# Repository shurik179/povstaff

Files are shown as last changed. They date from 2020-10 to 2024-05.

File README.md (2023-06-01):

# POV staff
This repository contains all files related to Persistence of Vision (POV) staff project. A detailed write-up of Version 1 of this project is available on  Instructables at [https://www.instructables.com/Persistence-of-Vision-LED-Staff/](https://www.instructables.com/Persistence-of-Vision-LED-Staff/); you can also find there photos  of the staff in action.

The latest version (as of June 1, 2023) is 4.1. It is documented at
https://povstaff.readthedocs.io

## Structure of this repository  
This repository is organized as follows:

* `docs`: documentation
* `code`: this directory contains the source code for the staff software
* `hardware`:  design files for the custom PCBs used in
  the project, as well as STEP files for the 3d printed components.
* `images`: sample image(s) and  `imagelist.txt` file

## Authors and license
This project was created by Alexander Kirillov <irobotics.store@gmail.com>; it is
based on [earlier work](https://learn.adafruit.com/pov-dotstar-double-staff) of
Phillip Burgess and Erin St Blaine from Adafruit. The project is available under
MIT license; see LICENSE file for details.

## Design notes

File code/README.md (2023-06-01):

# POV Staff Software

This folder contains software for POV Staff project, V4.  It is intended to be complied
and uploaded to the QT Py ESP32-S3 (or QT Py ESP32-S2) using Arduino IDE  version
1.8 or later.   You will need the following libraries:

  * POV-ESP32 library from  https://github.com/shurik179/pov-esp32

  * Adafruit DotStar

  * Adafruit NeoPixel

  * ESPxWebFlMgr from   https://github.com/holgerlembke/ESPxWebFlMgr

You will need the arduino core for ESP32, see https://learn.adafruit.com/adafruit-qt-py-esp32-s2/arduino-ide-setup
for installation instructions.

Make sure that you choose the following options in the Arduino IDE tools menu
(for ESP32-S3):

* Partition scheme: *Default (3MB APP/1.5MB SPIFFS)*

* Erase All Flash Before Sketch Upload: *Disabled*

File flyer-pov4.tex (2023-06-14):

% !TEX TS-program = pdflatex
% !TEX encoding = UTF-8 Unicode

% This is a simple template for a LaTeX document using the "article" class.
% See "book", "report", "letter" for other types of document.

\documentclass[10pt,letter, landscape]{article} % use larger type; default would be 10pt

\usepackage[utf8]{inputenc} % set input encoding (not needed with XeLaTeX)
\usepackage{graphicx} % support the \includegraphics command and options
\usepackage[T1]{fontenc}
\usepackage[scaled=1.0]{helvet}
\renewcommand*\familydefault{\sfdefault} %% Only if the base font of the document is to be sans serif

\usepackage[newdimens]{labels}
\LabelCols=3% Number of columns of labels per page
\LabelRows=2% Number of rows of labels per page
\LeftPageMargin=8mm% These four parameters give the
\RightPageMargin=8mm% page gutter sizes. The outer edges of
\TopPageMargin=8mm% the outer labels are the specified
\BottomPageMargin=8mm% distances from the edge of the paper.
\InterLabelColumn=0mm% Gap between columns of labels
\InterLabelRow=0mm% Gap between rows of labels
\LeftLabelBorder=6mm% These four parameters give the extra
\RightLabelBorder=6mm% space used around the text on each
\TopLabelBorder=6mm% actual label.
\BottomLabelBorder=6mm%
\numberoflabels=6
\LabelInfotrue
\LabelGridtrue

%\renewcommand{\baselinestretch}{1.2}

\begin{document}%
\genericlabel{%
\noindent\begin{minipage}{70mm}
    %\vspace*{-15mm}
\centerline{}
\medskip
\centerline{\Large\bf POV staff  kit V4}

\centerline{\tt{tindie.com/products/21633/}}

\medskip

Thank you for your order of POV staff kit! \\ Please visit \quad
{\tt povstaff.readthedocs.io}

for detailed instructions.

If you have any questions or comments, or need replacement for a part you have misplaced or damaged,  please email us at

\centerline{\tt{irobotics.store@gmail.com}}

%\medskip

To connect to the staff use WiFi network name and password below:

\vspace*{1.1cm}

Best, \\Island Robotics

\end{minipage}
}

\end{document}

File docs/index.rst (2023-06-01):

###############################
Persistence of Vision LED staff
###############################
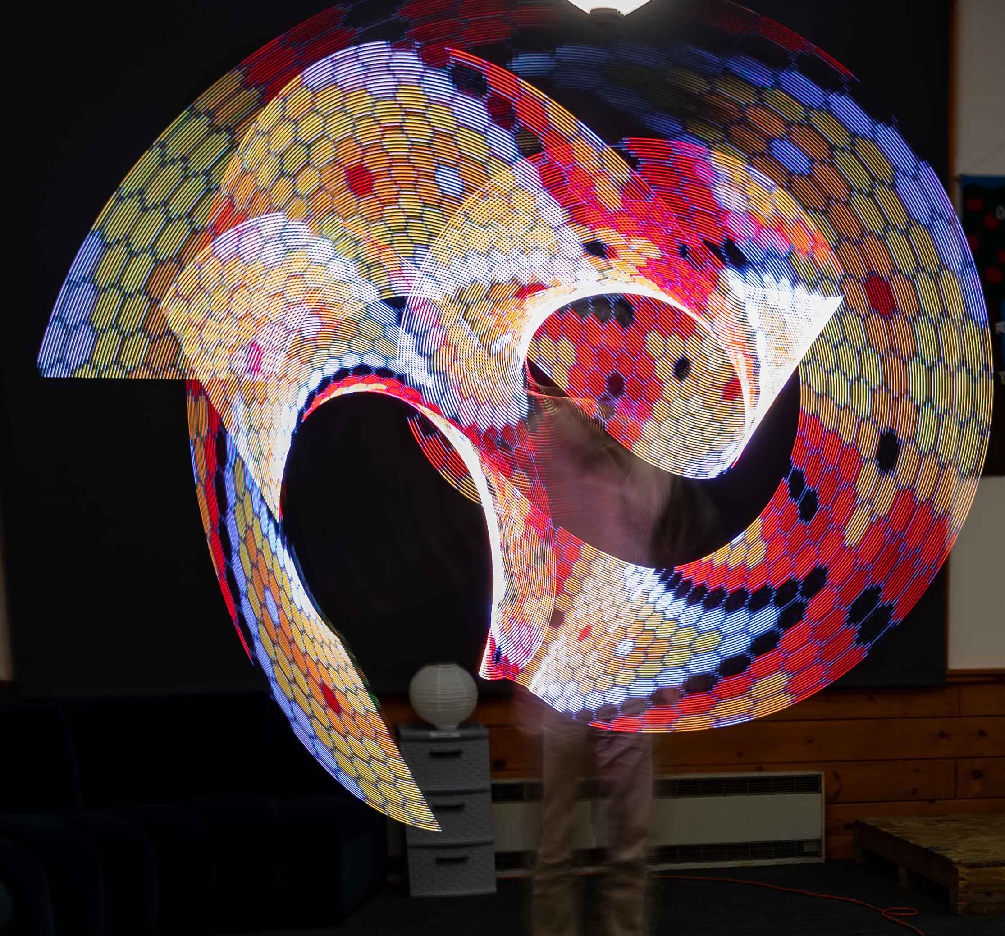
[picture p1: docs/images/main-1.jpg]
POV staff in action


This guide contains documentation for Persistence of Vision (POV) LED staff project,
created by Alexander Kirillov <irobotics.store@gmail.com>.

This document describes version 4.1, which was released on May 10, 2023.  An
earlier version of this project was documented on
`Instructables web site <https://www.instructables.com/Persistence-of-Vision-LED-Staff/>`__.
The version described here contains several improvements compared to the earlier
one, see below.

For those wishing to reproduce this project, we are offering a kit of parts for
sale through our `Tindie store <https://www.tindie.com/stores/irobotics/>`__.
However, all design files, software, BOM and more are published under open
source license, so anyone can build their own version from scratch. You can
find these files in the project GitHub repository: https://github.com/shurik179/povstaff

Overview
********

It is well known that even after a light has been turned off, human eye keeps
"seeing" it for a fraction of second. This is known as Persistence of Vision, or
POV, and it allows one to "paint" pictures by quickly moving a strip of LEDs,
drawing one line of an image at a time in quick succession. If you search online
(e.g. on Etsy), you can find quite a few toys based on this idea: pois, staffs, and more.

However, these are expensive: typical prices for a POV staff of decent
resolution start at $500, and they use proprietary software, so there is no easy
way to modify their behavior or add extra functionality. Thus, when looking for
a birthday gift for a friend who enjoys painting with light, I decided to create
my own open source version using readily available components.

My project builds upon the outstanding `work of Phillip Burgess and Erin St Blaine
<https://learn.adafruit.com/pov-dotstar-double-staff>`__
from Adafruit; however, I made a few changes, upgrading the electronics.

Key Features
************

* It is a two-sided staff, of total length 141 cm (55in); it is not collapsible.
  Each side of the staff has two 50cm/72 pixels LED strips, for the total of 288 LEDs.
  Thus, you can use it to show images with 72-px resolution.

* Staff is powered by two 18650 Li-Ion batteries, which should be enough for at
  least 1 hr show, possibly as much as 2 hours, depending on intensity of your
  images. The batteries can be recharged via 5.5mm/2.1 barrel connector (or USB
  C cable, using included adapter); full charge time is about 5 hrs.

* Images (in bitmap format) can be easily uploaded to the staff over WiFi. It has
  enough memory for about 50 images. The order in which images are shown is
  described in a separate plain text file, where you can put a list of
  images and durations. An image can be listed there several times, or none at all.

* The staff contains an Inertial Motion Unit (IMU) which can be used to detect
  when the staff is in motion. The software uses it to adjust update frequency
  for images, so the images will not appear stretched or compressed regardless
  of how fast you are rotating it. You can also use it for controlling your
  show: e.g. stopping the staff vertically is used as a signal to move to the
  next image in the slideshow.

* The software is based on Arduino IDE. It is available under an open source
  license and is easy to modify to suit your needs.

Differences from  version 3
****************************

* New MCU (ESP32-S3 QT Py)

* Wireless uploading of images

* Many changes to wiring

* New 3d printed spacers and other components, printed in black resin.

* Foam protectors at the ends of the staff, to protect the staff when dropped

.. toctree::
    :caption: Table of Contents
    :maxdepth: 2

    build
    usage
    license

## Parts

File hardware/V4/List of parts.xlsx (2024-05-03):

 | Name | Needed per kit | Price per kit | Vendor | URL
 | QT Py ESP32-S3 | 1 | $11.25 | Adafruit | https://www.adafruit.com/product/5426
Electronics | POVshield |  | $4.00 | JLCPCB
 | POVswitchboard |  | $1.00 | JLCPCB
 | PDB-switch |  |  | JLCPCB
 | PDB-charge |  |  | JLCPCB
3d printed | battery midspacer | 1 | $1.40 | JLCPCB 3d print
 | battery endspacer | 2 | $2.80 | JLCPCB 3d print
 | Charge spacer | 1 | $2.20 | JLCPCB 3d print
 | Switch spacer | 1 | $2.20 | JLCPCB 3d print
 | Endspacer - charge | 1 | $2.40 | JLCPCB 3d print |  | Printed in black resin
 | Endspacer-switch | 1 | $2.40 | JLCPCB 3d print
 | tool |  |  | DIY
Connectors | 2x3header, male | 2 | $1.30 | Digikey | https://www.digikey.com/en/products/detail/samtec-inc/TSW-103-08-F-D/6691696
 | 2x3 header female, 90 deg | 2 | $1.80 | Digikey | https://www.digikey.com/en/products/detail/samtec-inc/SSQ-103-02-T-D-RA/1111310
 | 7 pin male hader, 11.4 mm long, double spacer | 2 | $1.00 | Aliexpress | https://www.aliexpress.us/item/2251832709911024.html
 | switch | 1 | $0.92 | Mouser | https://www.mouser.com/ProductDetail/612-RRA1534400
 | Charge connector |  | $0.30 | Aliexpress | https://www.aliexpress.us/item/3256802811672166.html
 | USB C to barrel plug adapter |  | $1.00 | Aliexpress | https://www.aliexpress.us/item/3256804389121490.html
Wires | 2-pin XH pigtails | 2 | $0.90 | Amazon | https://www.amazon.com/gp/product/B096F5LSVL
 | 4-pin 22 AWG wire | 22 cm |  | Aliexpress | https://www.aliexpress.us/item/2255800087895459.html
 | 2-pin 20 AWG wire | 55.5cm |  | Aliexpress
 | 2-pin 24 AWG wire | 55.5 cm |  | Aliexpress
LED | SK9822 LED strip, 144pixels/m,black, IP30 | 2 | $34.00 | Aliexpress | https://www.aliexpress.us/item/2251832136012227.html | https://www.aliexpress.us/item/3256805036306271.html
End protection | Foam tubing, 28mm ID, 38mm OD | 2x3cm | $1.30 | Amazon | https://www.amazon.com/gp/product/B0951ZLSJL
 | Heat Shrink Wrap Tubing, 40mm diameter, black | 2x5.5cm | $1.00 | Amazon | https://www.amazon.com/gp/product/B07FVRT9JS
 | Tennis Overgrip tape | 1 pc | $2.00 | Amazon | https://www.amazon.com/gp/product/B001OTC4K0/
Total |  |  | $75.17

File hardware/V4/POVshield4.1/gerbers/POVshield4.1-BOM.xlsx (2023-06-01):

Designator | Footprint | Comment | JLCPCB Part #（optional）
C1,C2,C3 | C_0805_2012Metric | 10uF | C15850
C4,C5 | C_0603_1608Metric | 100nF | C14663
D1 | LED_0603_1608Metric | LED | C72038
R1 | R_0603_1608Metric | 2k | C22975
R2 | R_0603_1608Metric | 1.2k | C22765
R3,R4,R5 | R_0603_1608Metric | 3.3k | C22978
R6,R7 | R_0603_1608Metric | 10k | C25804
U2 | Bosch_LGA-14_3x2.5mm_P0.5mm | LSM6DSO | C2829074
U1 | HSOP-8-1EP_3.9x4.9mm_P1.27mm_EP2.41x3.1mm_ThermalVias | TP4056 | C16581

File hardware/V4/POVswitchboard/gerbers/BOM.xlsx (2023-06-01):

Designator | Footprint | Comment | JLCPCB Part #（optional）
C2 | C_0805_2012Metric | 10uF

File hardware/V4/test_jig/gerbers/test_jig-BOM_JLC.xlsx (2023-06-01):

Comment | Designator | Footprint | JLCPCB Part #（optional）
SK9822-EC2020 LED | D1,D2,D3,D4,D5,D6,D7,D8,D9,D10,D11,D12,D13,D14,D15 | 2020 | C2909059

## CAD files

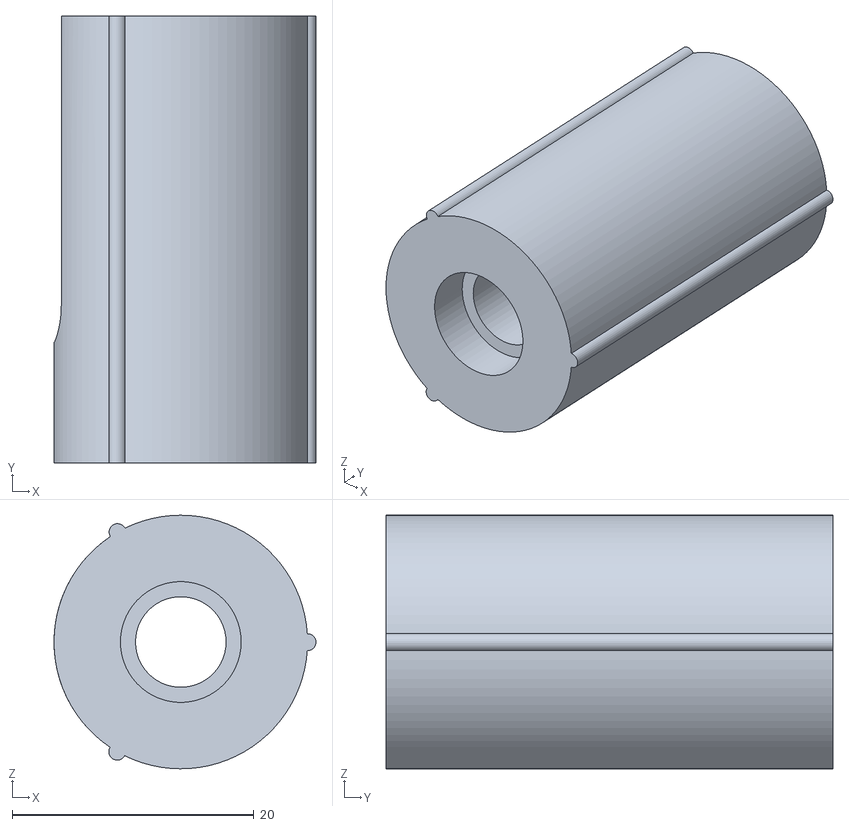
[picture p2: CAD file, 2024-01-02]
hardware/V4/3d-printed/Charger_spacer_2024.01.02.stl
21.7 x 37.0 x 21.0

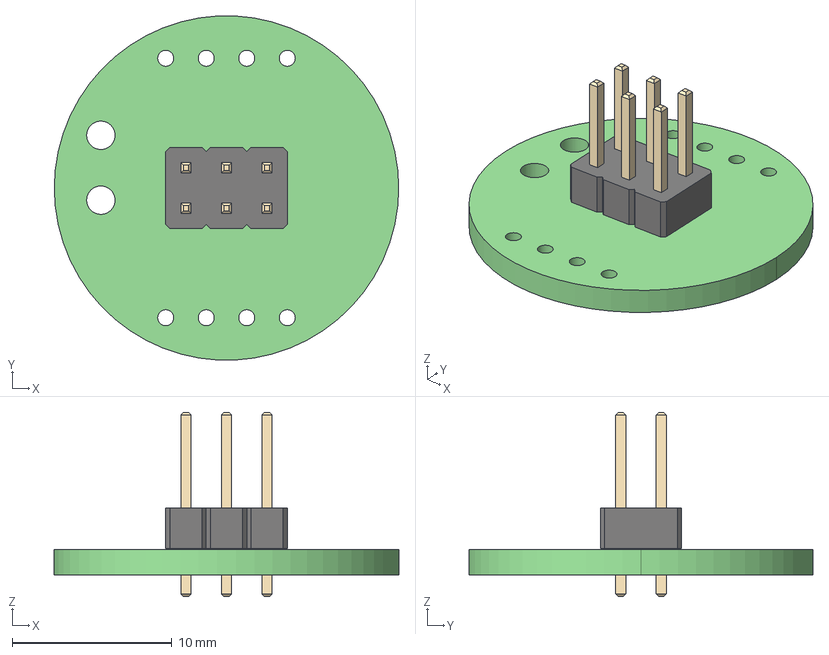
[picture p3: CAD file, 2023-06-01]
hardware/V4/PDB4-CHARGE/PDB4-CHARGE.step
21.6 x 21.6 x 11.5 mm
PDB4-CHARGE PCB

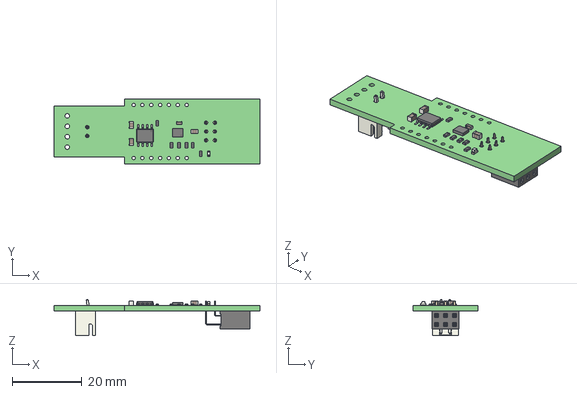
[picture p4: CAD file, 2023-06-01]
hardware/V4/POVshield4.1/POVshield4.1.STEP
59.2 x 18.8 x 10.4 mm
_autosave-POVshield4 PCB

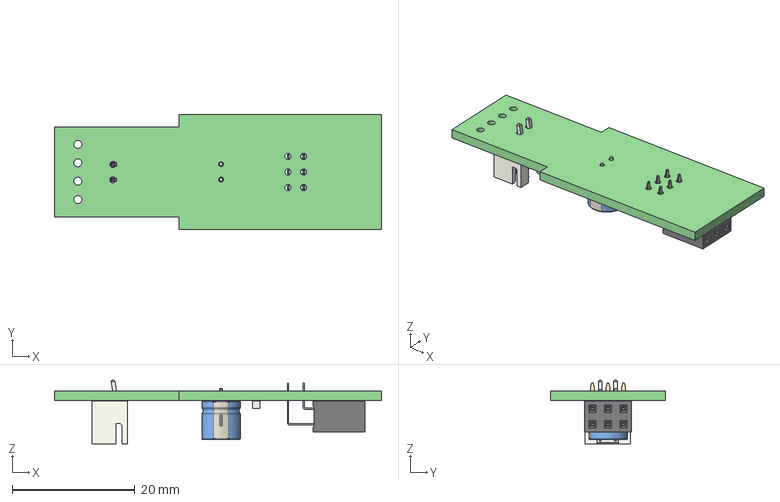
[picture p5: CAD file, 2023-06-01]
hardware/V4/POVswitchboard/POVswitchboard.STEP
53.3 x 18.8 x 10.4 mm
POVswitchboard PCB

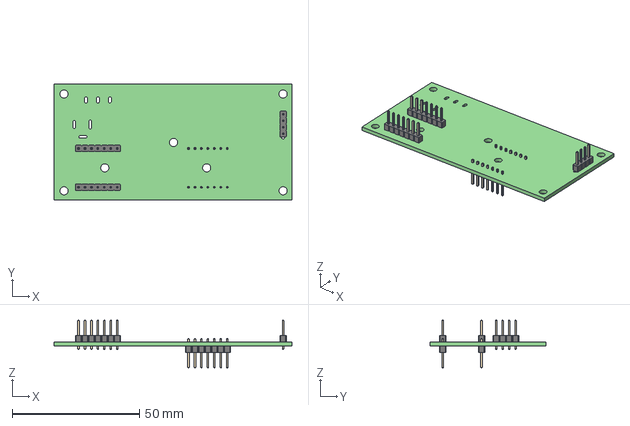
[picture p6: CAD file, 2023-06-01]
hardware/V4/test_jig/test_jig.STEP
93.4 x 45.7 x 18.8 mm
test_jig PCB

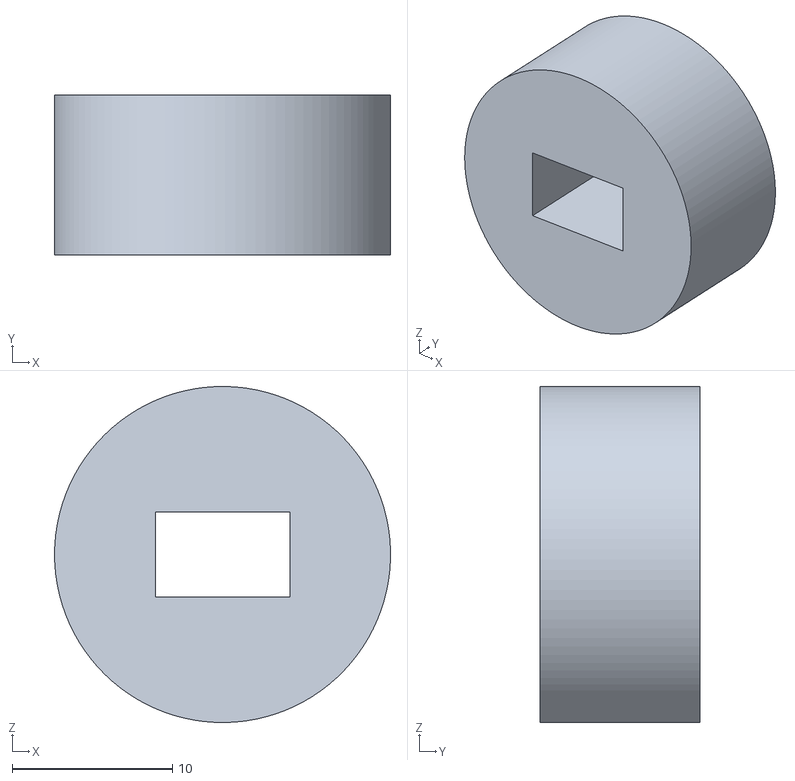
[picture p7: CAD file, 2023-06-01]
hardware/V4/3d-printed/PDB tool_2023.04.26.stl
21.0 x 10.0 x 21.0

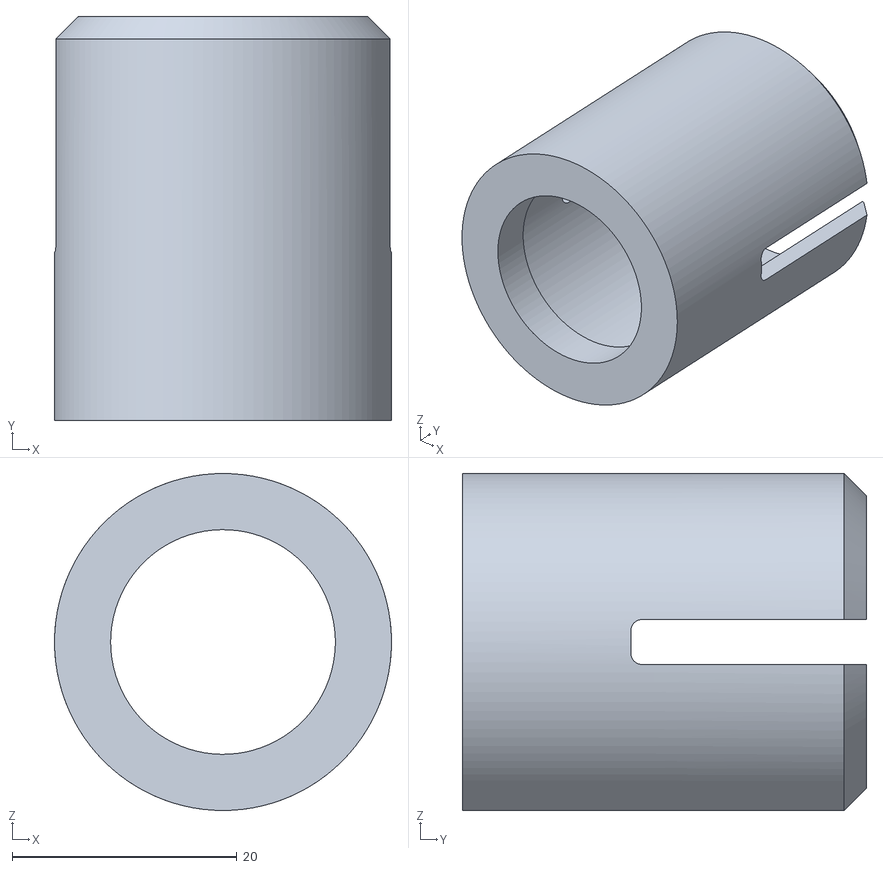
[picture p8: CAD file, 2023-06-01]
hardware/V4/3d-printed/Endcap_switch_2023.04.26.stl
30.0 x 36.0 x 30.0

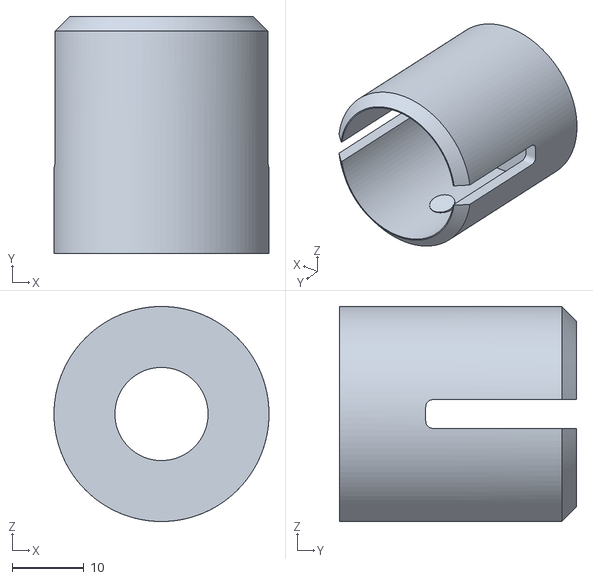
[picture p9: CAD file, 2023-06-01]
hardware/V4/3d-printed/Endcap_charger_2023.04.26.stl
30.0 x 33.0 x 30.0

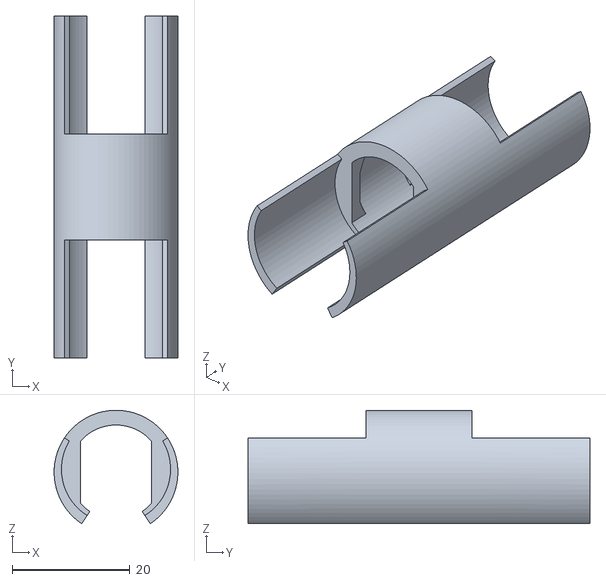
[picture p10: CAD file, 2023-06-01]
hardware/V4/3d-printed/Battery_midspacer_2023.04.26.stl
21.0 x 58.0 x 19.2

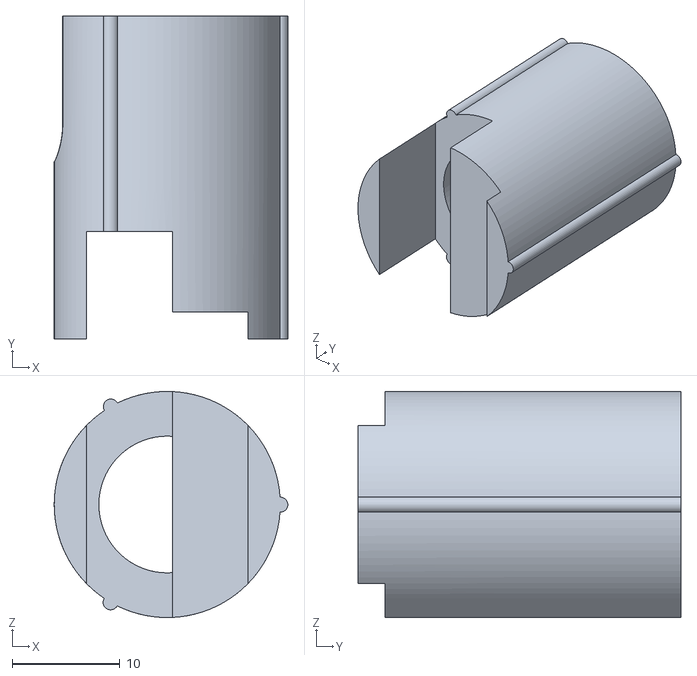
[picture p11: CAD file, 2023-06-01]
hardware/V4/3d-printed/Switch_spacer_2023.04.26.stl
21.7 x 30.0 x 21.0

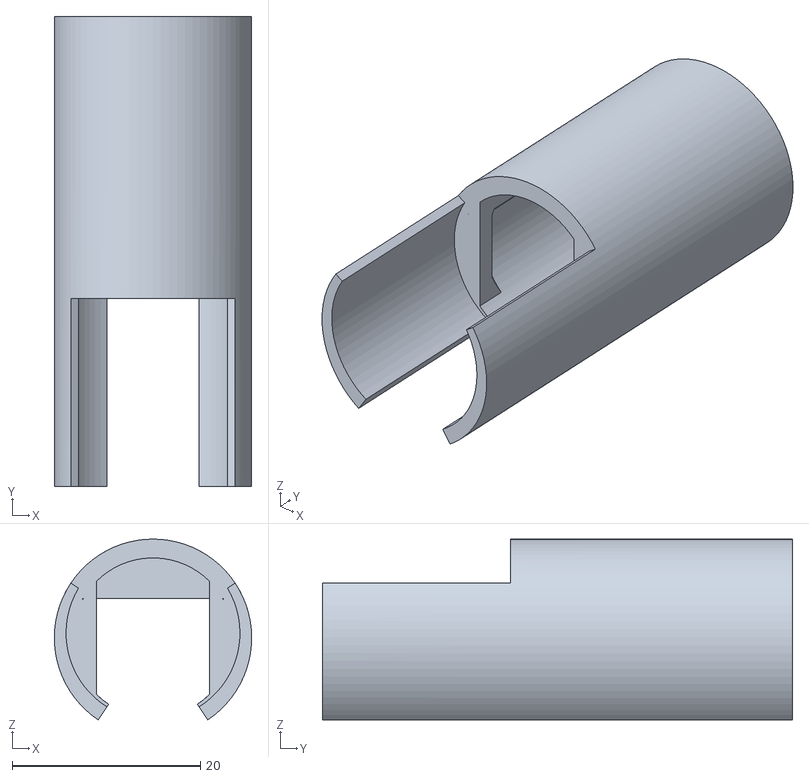
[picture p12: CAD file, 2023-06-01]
hardware/V4/3d-printed/Battery_endspacer_2023.04.26.stl
21.0 x 50.0 x 19.2

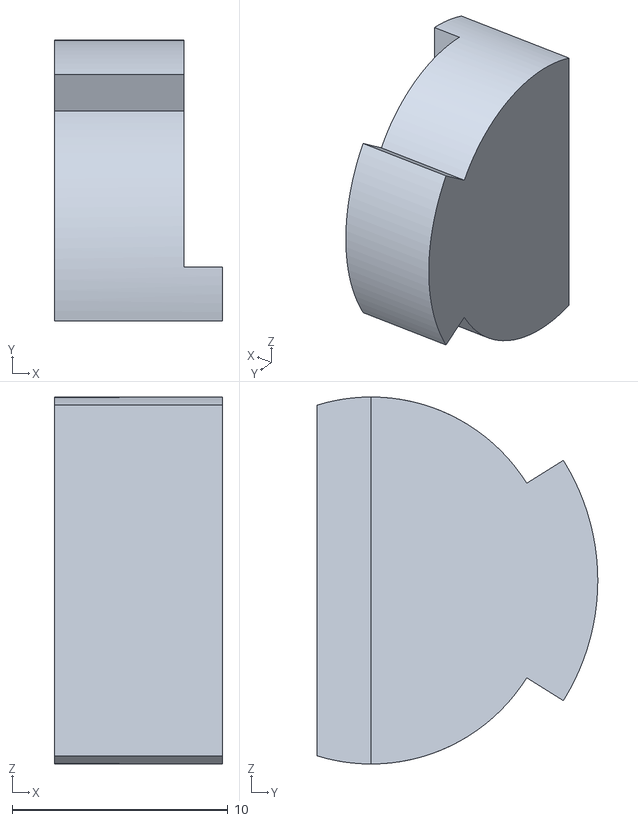
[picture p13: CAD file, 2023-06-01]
hardware/V4/3d-printed/plug_2023.04.26.stl
7.80 x 13.0 x 17.0

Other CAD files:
hardware/V4/3d-printed/Battery_endspacer_2023.04.26.f3d
hardware/V4/3d-printed/Battery_midspacer_2023.04.26.f3d
hardware/V4/3d-printed/Charger_spacer_2024.01.02.f3d
hardware/V4/3d-printed/Endcap_charger_2023.04.26.f3d
hardware/V4/3d-printed/Endcap_switch_2023.04.26.f3d
hardware/V4/3d-printed/PDB tool_2023.04.26.f3d
hardware/V4/3d-printed/Switch_spacer_2023.04.26.f3d
hardware/V4/3d-printed/plug_2023.04.26.f3d

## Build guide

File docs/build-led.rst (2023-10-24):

Step 2: LED assemblies
======================

**Materials and tools:**

* Wood dowels with attached PDBs (from step 1)

* LED strips

* 22AWG solid core wire (from bag A in kit of parts)

**Steps:**

1. Get the LED strip(s). If they have any wires soldered, de-solder them; remove
   excess solder using a braid wick. If you ordered 1m or 2m strips, cut them into
   50 cm pieces, making sure to leave as large as possible soldering pads in the
   beginning of each strip (this should be easy, as usually longer strips are
   created by soldering together 50cm ones, so you will be just undoing someone
   else's work).

2. Tin the pads in the beginning of each LED strip.
   **Warning: LED strips are directed!! in each strip, the signal goes in one
   direction only, as indicated by the arrows. You should tin the pads in the
   beginning of the strip, so that arrows go from tinned pads to the opposite
   end - see photos below.** 

3. Solder 2cm long pieces of 22AWG wire to each of the pads. The easiest way to
   do it is as follows:

   * Strip 2cm of insulation from the end of wire; do not cut it yet.

   * Holding the wire by insulated part, solder the stripped end to the pad.
     You will be soldering very close to the first LED, so please watch your
     iron carefully - do not touch the LED!

   * Cut the wire. To make the next steps easier, trim the wires so that they
     are of different lengths (length of each should be at least 1 cm)

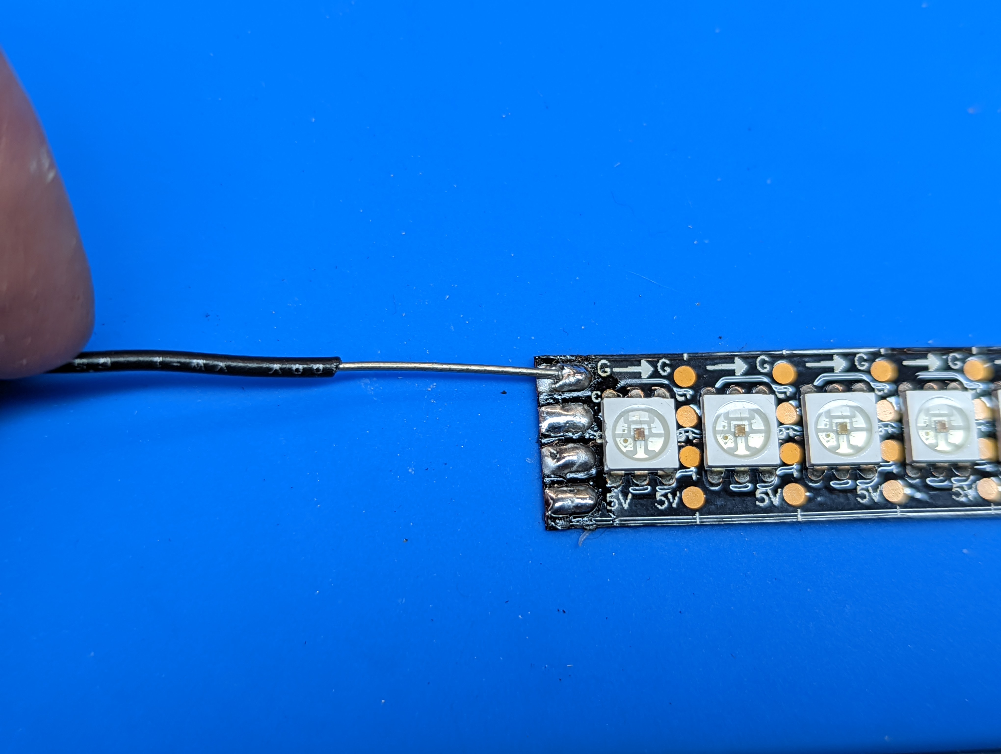
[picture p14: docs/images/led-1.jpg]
    

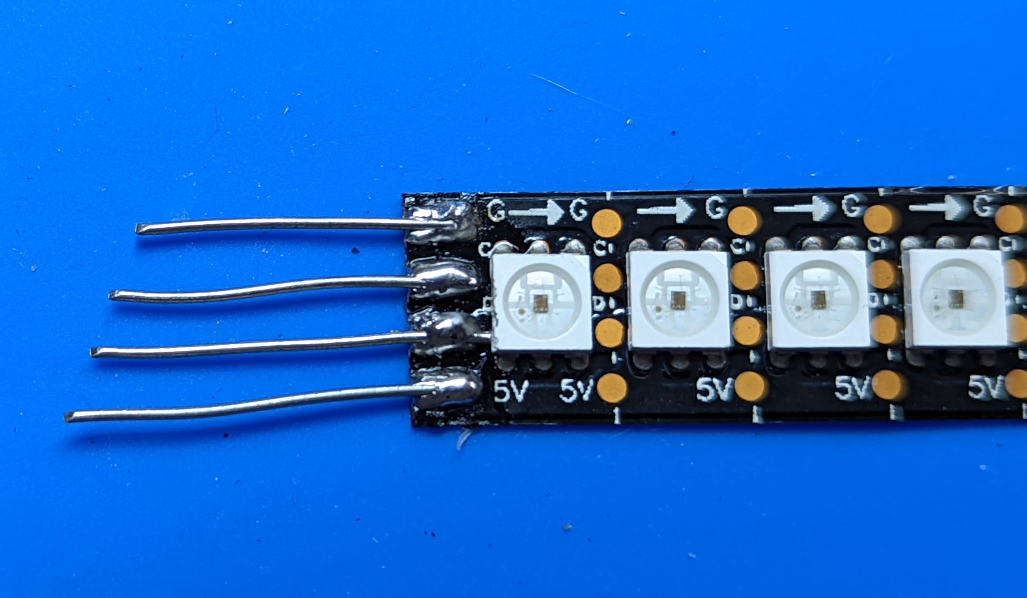
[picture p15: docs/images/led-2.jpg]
    

4.  Remove  the  backing paper from the first 5-10 cm of adhesive strip on the back
    of the LED. Insert the soldered wires into the holes of the power distribution
    board you had previously attached to the wood dowels and
    attach the strip to the wood dowel, aligning it so that the
    beginning of the strip is about 5mm away from the power distribution board.
    Remove the remaining backing paper and attach the strip to the dowel.

5.  Solder the wires to the power distribution board. Trim them using flush cutters.
    Repeat the previous steps for all 4 LED strips, placing two LED strips on
    each dowel, on opposite sides of the dowel.

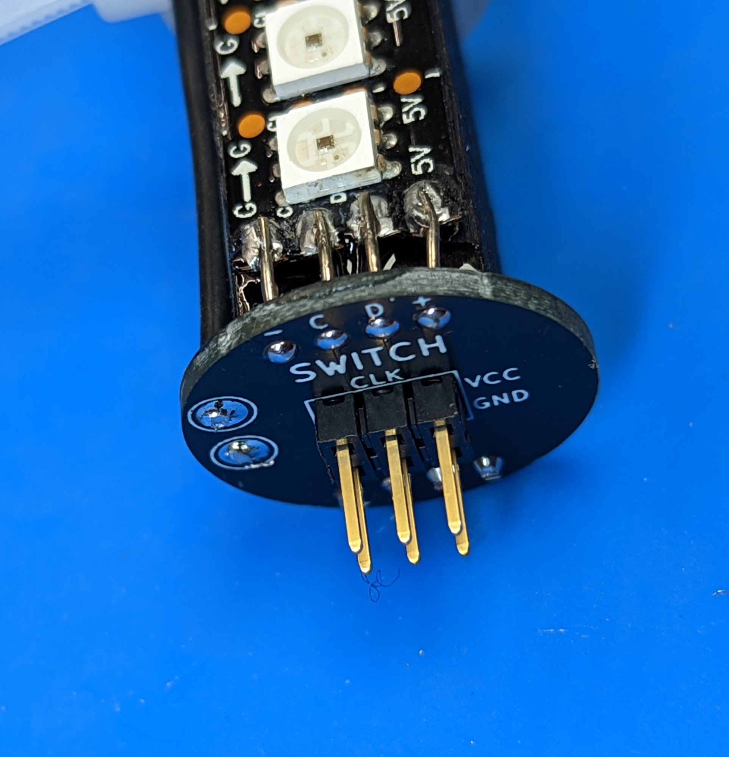
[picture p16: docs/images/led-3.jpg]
   

**Note**: the adhesive on LED strips is not very strong, so your strips might
start peeling off. It is OK; we will make a more permanent attachment later.

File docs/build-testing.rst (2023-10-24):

Step 8: Testing
===============================
Before continuing, let us do the final test. Make sure to clear large area on
your desk or floor for this step.

Take the controller assembly you had created in the previous step and plug it
into the LED assemblies as follows:

* The POV controller shield with the QT Py should be plugged into the LED assembly
  labeled CHARGE.

* The switch connector  board should be plugged into the LED assembly labeled SWITCH

**The LED assemblies are not interchangeable!**

In each case, the board must be plugged into PDB so that the label CHARGE (or SWITCH)
should be above the plugged board:

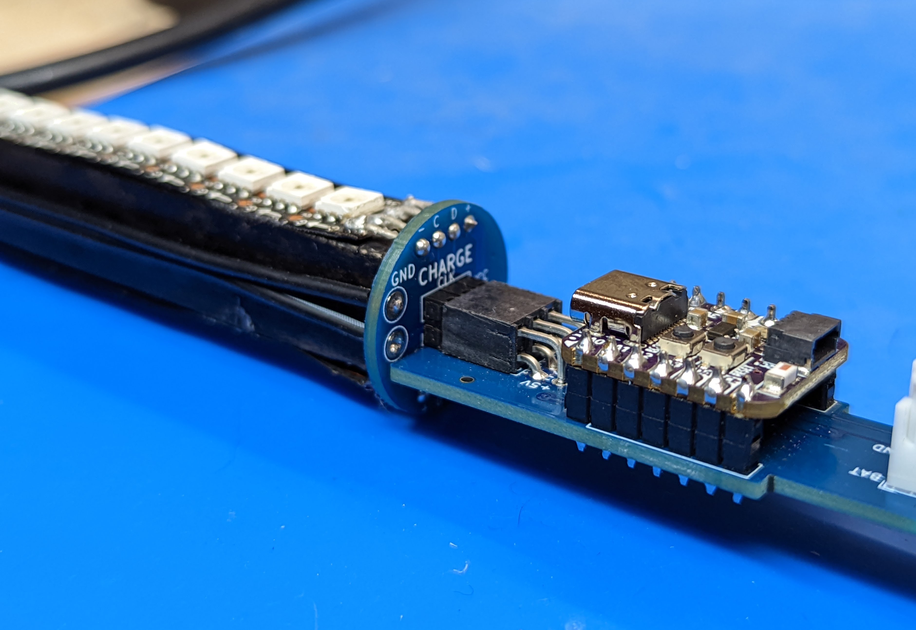
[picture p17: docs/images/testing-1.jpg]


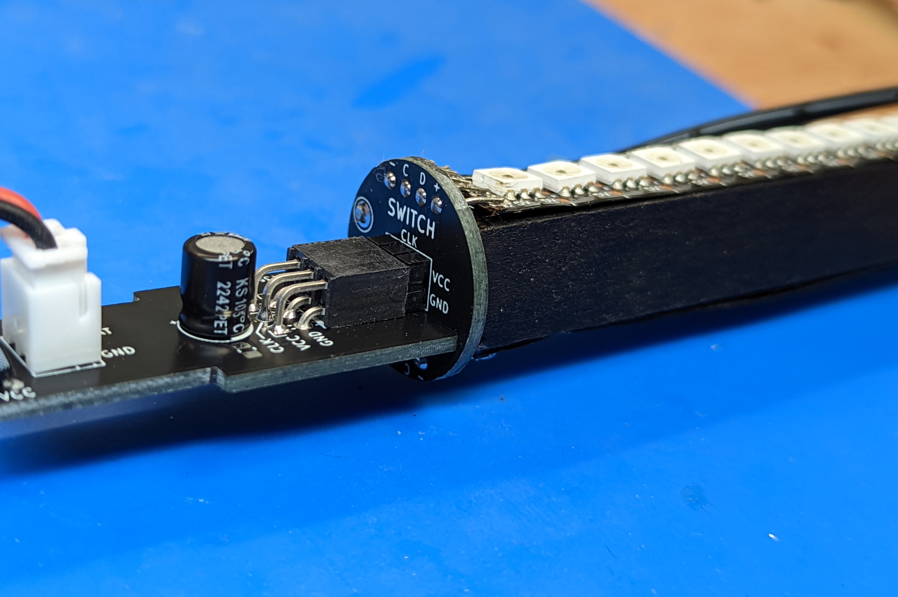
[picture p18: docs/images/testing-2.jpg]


Double-check that everything is plugged correctly. Make sure that the switch at
the end of SWITCH LED assembly is in the middle (Off) position.

Now, take the batteries. Plug the battery connectors into the 2-pin JST XH
connectors on the POV shield board and the switch board (doesn't matter which battery goes into which board).

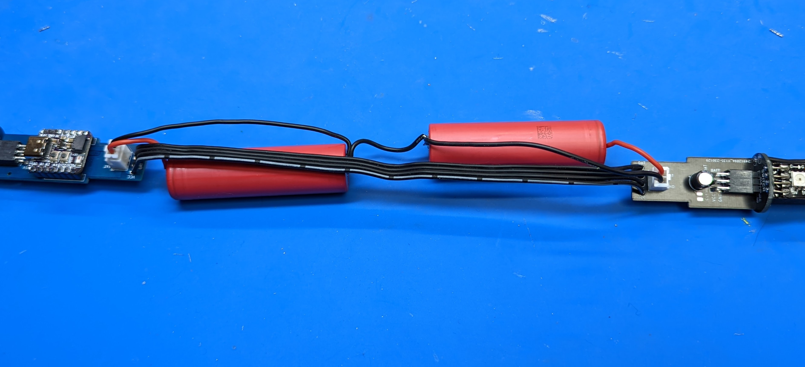
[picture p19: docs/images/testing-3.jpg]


Turn the switch on (you will have to try both positions to figure out which of them is ON).

The staff should come to life; it will show the battery voltage, by
lighting part of the LED strips. The longer the strip, the higher the battery charge.

Note: the software uses the motion sensor (IMU). If you turn the staff on while the
staff (to be precise, the electronics board containing the motion sensor) is horizonal,
the staff goes into charging mode, so it will show the battery voltage but will not
show any images. If you want to test images, make switch the staff on holding
the sensor board vertical. See User guide for details.

If this works, you can turn the staff off and  proceed to the next step.

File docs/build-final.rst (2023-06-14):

Step 10: Final assembly
===============================

**Materials:**

* LED assemblies, from previous steps

* battery and controller assembly, from step 9

* bag F:

  Kit of parts, bag F

  1.  two shrink wrap sleeves

  2. two foam sleeves

  3. Switch end protector

  4.  Charge  end protector

  5. tennis grip tape

  6. Foam washers

* Clear polycarbonate tube (11F/141 cm), from flowtoys.com

**Steps:**

1. Make sure you have a large area to work.
   Lay out the LED assemblies, battery and electronics assembly. Make sure that
   the switch at the end of SWITCH LED assembly is in middle (OFF) position.

2. Plug the battery assembly into the LED assemblies. As before, the side which
   contains QT Py MCU should be plugged into the CHARGE LED assembly, and the
   other side, into the SWITCH LED assembly. In each case, the board must be
   plugged into PDB so that the label CHARGE (or SWITCH) should be above the
   plugged board:

   Connecting LED assemblies

   Connecting LED assemblies

3. Double-check that everything is plugged correctly. Do the final test: turn
   the switch on. The LEDs should briefly light up, showing the battery charge.
   If they don't, check the troubleshooting section.
   If everything is OK, turn the switch off and proceed.

4. Start inserting the whole assembly into the tube, CHARGE end  first. Do it
   slowly. If you meet with resistance, push gently; if it is not enough, do
   not use excessive force - try to locate the problem. If necessary, remove
   from the tube and fix the wiring or electric tape. Watch that the LED assembly
   does not get  disconnected from the battery and electronics assembly.
   Continue until everything is fully in. Push to fully insert the switch; make
   sure the switch retaining tabs are inside the tube.
   If everything worked as expected, the charge connector should now be level with the
   opposite end of the tube or several millimeters inside the tube. In the
   latter case, use the included foam washers to fill the rest of the tube.

5. Take the 3d printed switch end protector (item 3 in bag F, the one with larger
   opening). For shipping, it might have been placed inside the foam wrap;
   if so, remove it from the foam wrap.  Put it over the
   switch end of tube. There are two small bumps inside the protector which
   should go into the holes in the tube; if necessary, turn the end protector
   until you hear the click.

6. Repeat the same with the charge switch protector (item 4 in the bag), putting it
   on the opposite end of the tube. Test the whole staff once again, turning it
   on and off.

7. Put the two pieces of the foam tube over the end protectors so that the foam
   tube extends beyond the protector by 2-3 mm. In 2-3 places, put some epoxy (or crazy glue)
   between the foam and the 3d-printed  end protector. 

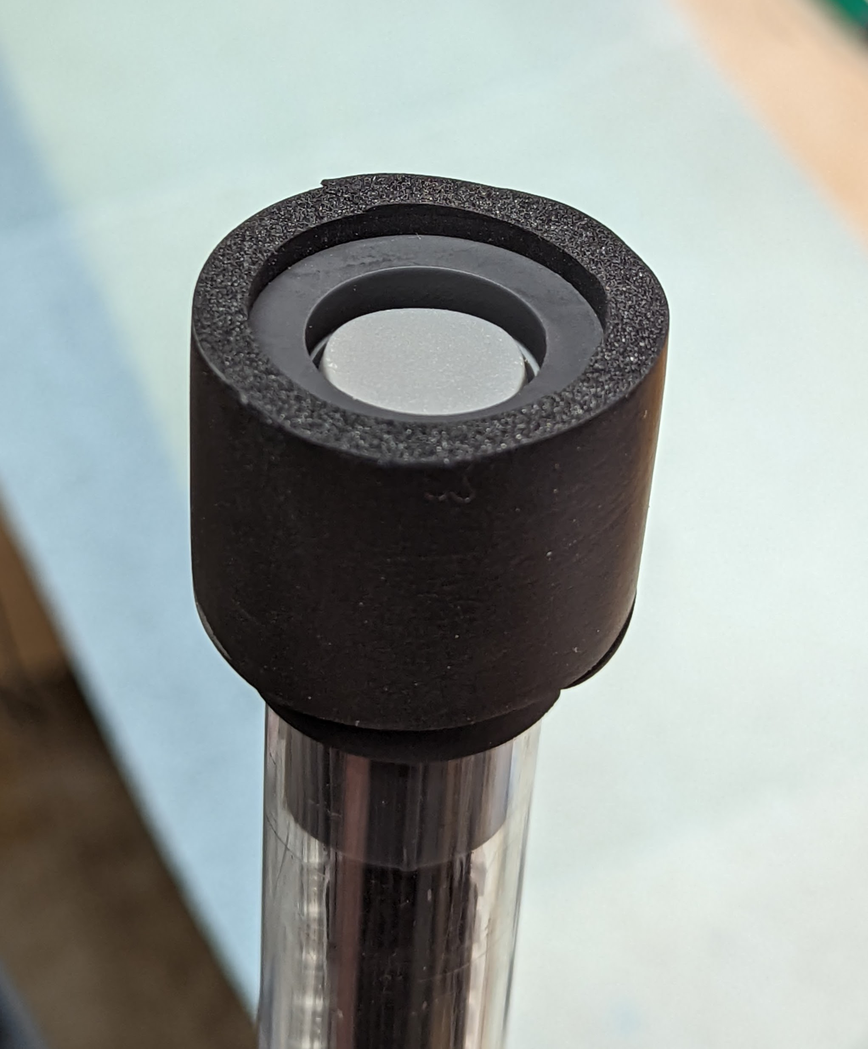
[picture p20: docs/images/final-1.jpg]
   

8. Put the shrink wrap over the foam as shown in the photo below. It should
   extend beyond the end of the foam wrap by another 5 mm

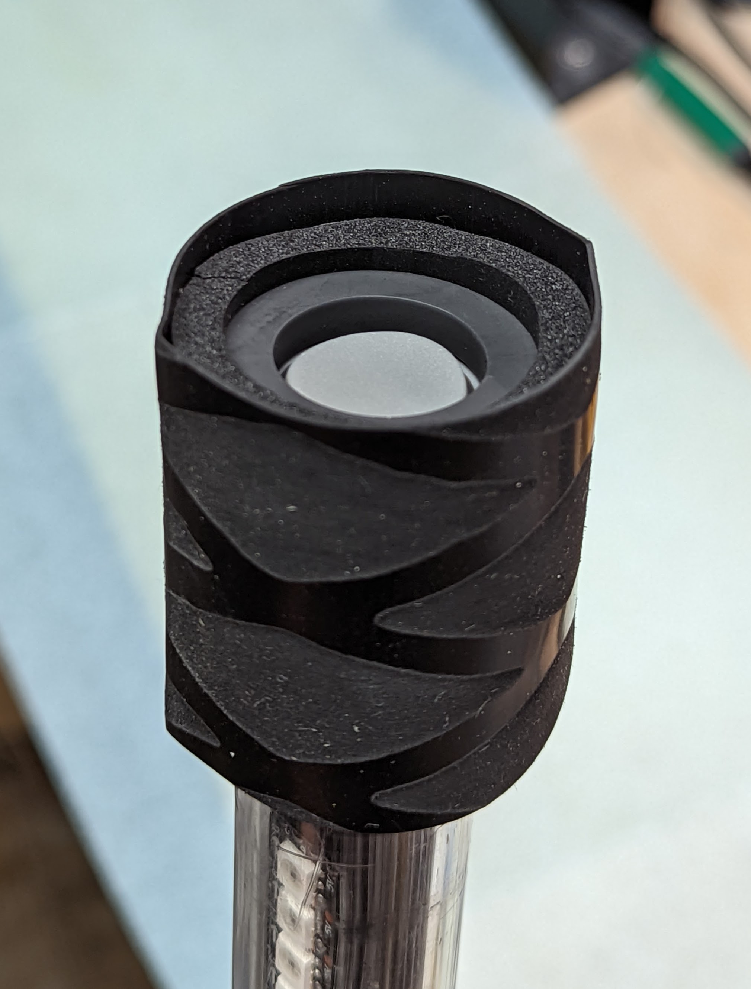
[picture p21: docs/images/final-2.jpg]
   

9. Use heat gun (on low setting) to shrink  the shrink wrap.

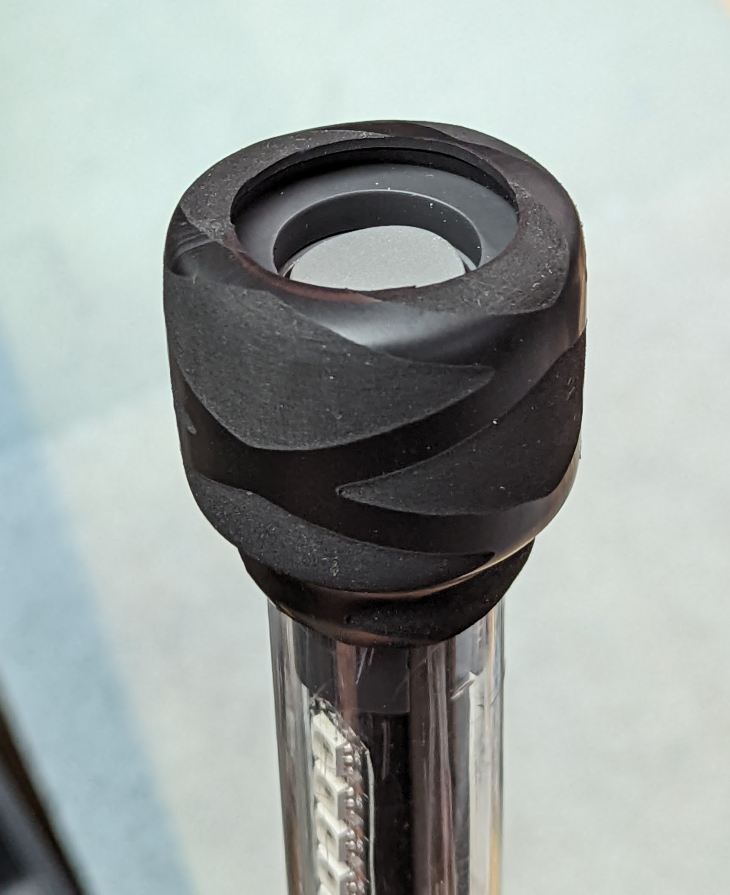
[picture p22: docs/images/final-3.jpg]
   

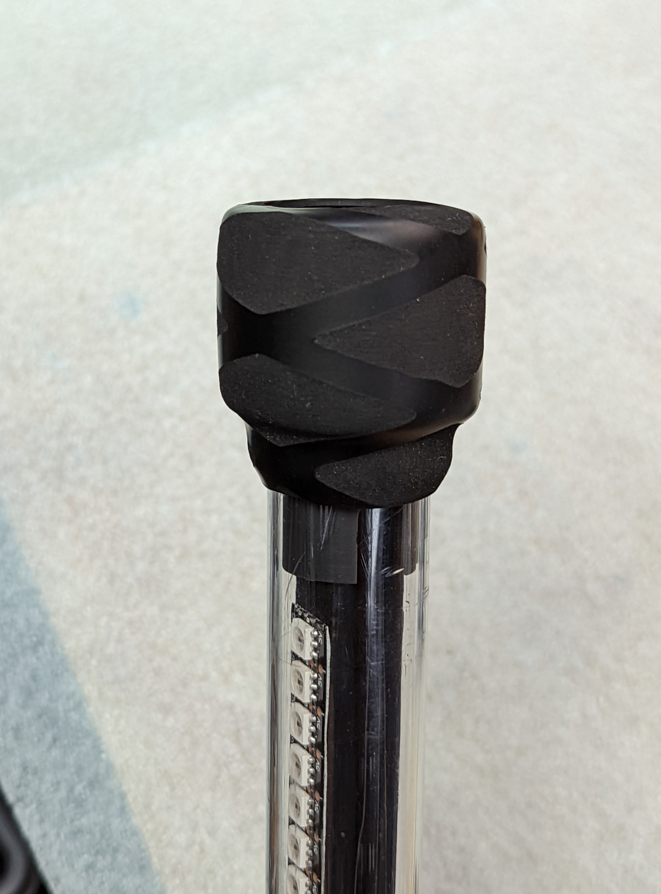
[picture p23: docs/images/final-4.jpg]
   

10. Apply the tennis overgrip tape over the middle part of the tube,
    containing the battery and electronics assembly  - everything between the
    ends of LED assemblies. You can watch this video to see the proper
    way of applying the overgrip tape:
    https://www.youtube.com/watch?v=HNc34XlUBww. Make sure to keep the overlaps
    between tape turns small - if you make them too large, your tape will run out
    before you reach the end of battery assembly.

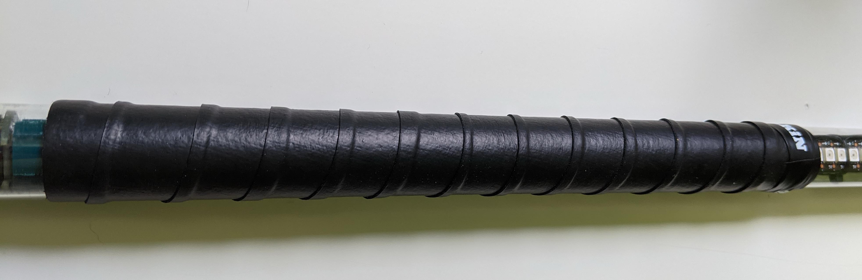
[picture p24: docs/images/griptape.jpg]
Grip tape
    

This completes your staff assembly - congratulations!!

Please check the User Guide for instructions on using your staff.

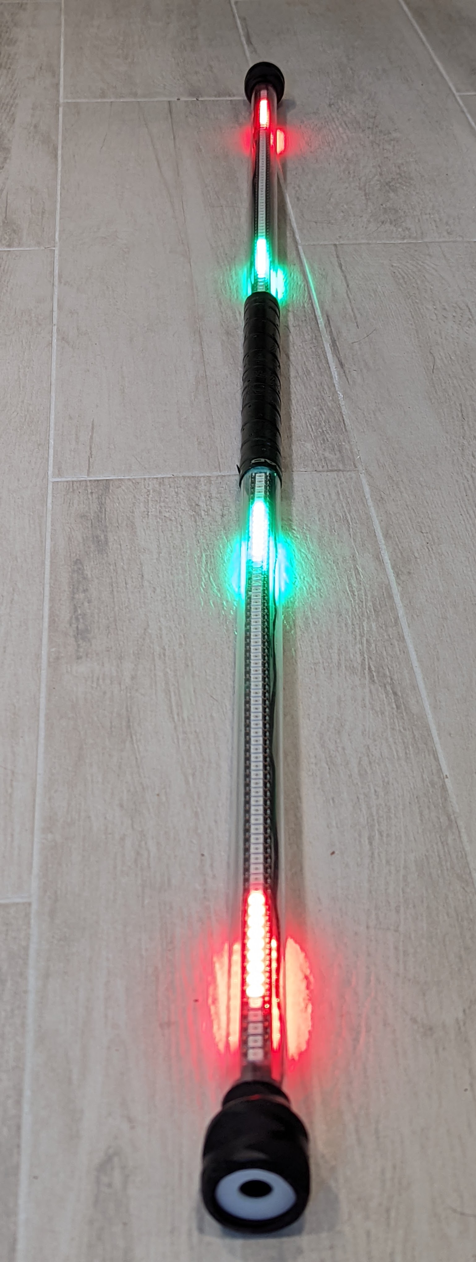
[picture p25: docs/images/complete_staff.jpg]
Complete staff


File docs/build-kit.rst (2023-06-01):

Kit of parts
============
Below is listing of parts included in the kit sold on Tindie.

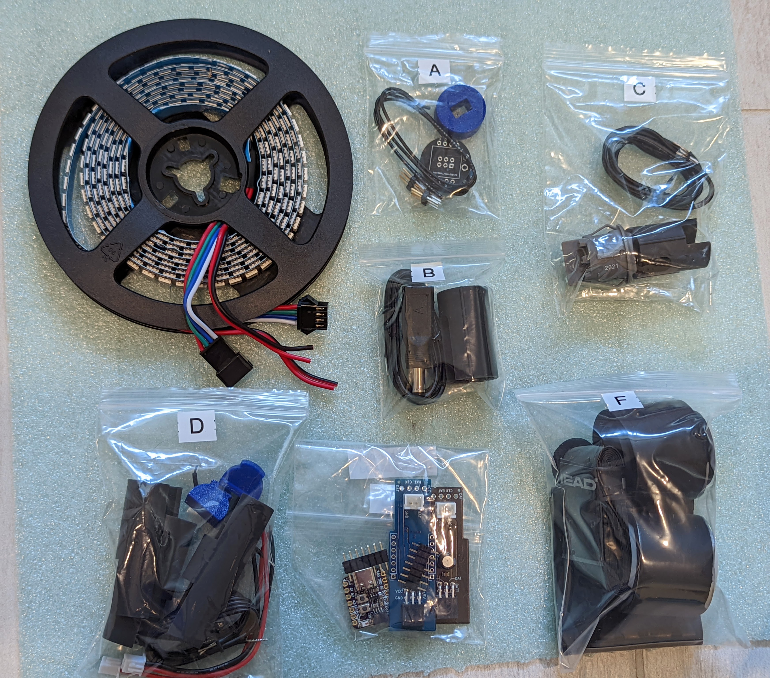
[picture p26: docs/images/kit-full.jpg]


* LED strips (2m, 144 LED/m APA102 or compatible, black PCB)

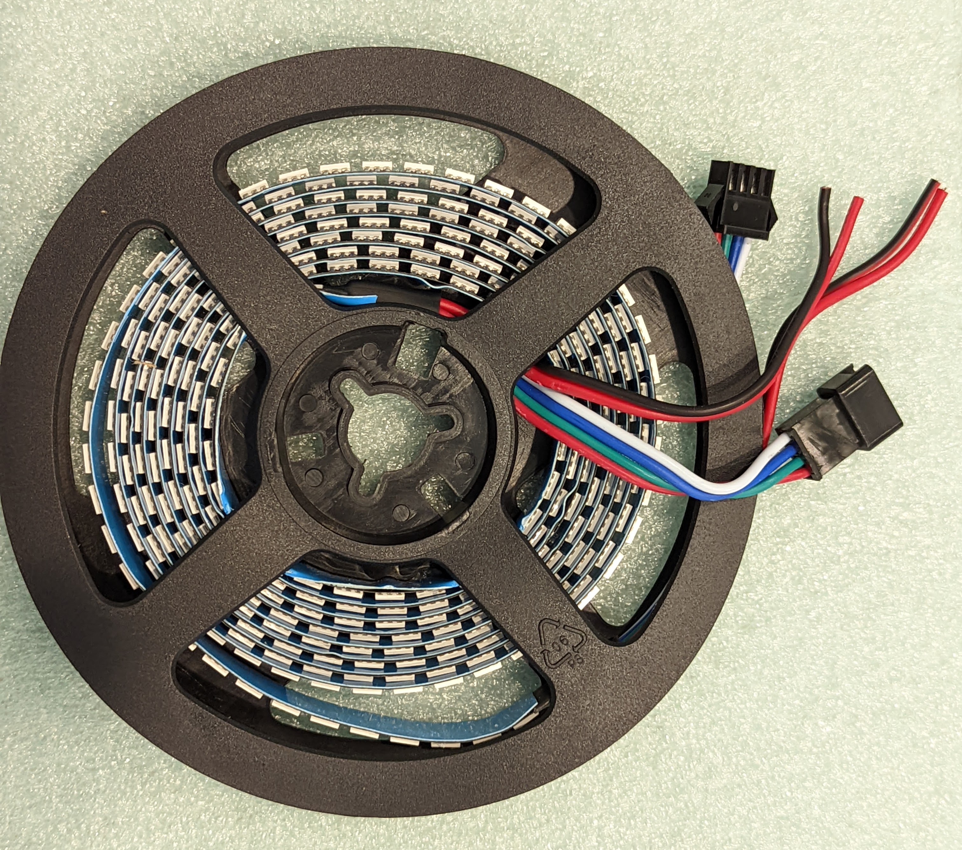
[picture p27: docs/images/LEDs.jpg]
  

* **Bag A**: materials for LED assemblies

  Kit of parts

  1. two power distribution boards (PDB),

  2. two  2x3 pin headers (to be soldered to the PDBs)

  3. 22AWG solid core wire (to be soldered to LED strips)

  4.  3d printed press tool, to be used for pressing the PDBs into the dowels. Discard after use

  Note: color of the wire and press tool may vary.

* **Bag B**:

  Kit of parts, bag B

  1. Charge connector

  2. 3d printed housing for charge connector

  3. 2-pin wire (55 cm, 24 AWG)

  4. Charging adapter (USB C to 5.5mm barrel jack)

* **Bag C**:

  Kit of parts, bag C

  1. Switch

  2. 3d printed housing for the switch

  3. 2-pin wire (55cm, 20 AWG)

* **Bag D**: battery assembly components

  Kit of parts, bag D

  1. two 2-pin wires, with JST XH connector

  2.  3d printed spacer, to go between batteries

  3. Two 3d printed spacers to go at the ends of batteries

  4. 3d printed "plugs"

  5. 4-pin wire (22cm, 22AWG)

  6. Wire,  5.5 cm, 22 AWG

* **Bag E**: electronics

  Kit of parts, bag E

  1. QT Py ESP32-S3 MCU, preprogrammed

  2. Custom-made POV controller board (blue), containing Inertial Motion Unit, battery
     charge circuit, and more.

  3. Switch  connector board (black)

  4. Two 7-pin headers

* **Bag F**:

  Kit of parts, bag F

  1.  two shrink wrap sleeves

  2. two foam sleeves

  3-4.  two 3d printed end protectors

  5. tennis grip tape

  6. Foam washers

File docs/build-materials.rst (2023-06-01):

Tools and materials
===================

You will need the following materials:

* `Kit of parts <https://www.tindie.com/products/irobotics/pov-staff-kit/>`__ from
  my Tindie store, version 4.

*  Two **18650 Li-Ion batteries**. Look for high-capacity (at least 3000mAh),
   **unprotected** batteries from a reputable manufacturer such as Panasonic, Samsung,
   or Sanyo. Do not try to save money by buying no-name battery on eBay or Amazon;
   instead, use a specialized  store such as `18650batterystore.com <http://18650batterystore.com>`__.
   Batteries must be **identical**, ideally from the same batch. Current rating
   (5A/10A/20A) doesn't matter much for this project. I used
   `these batteries <https://www.18650batterystore.com/products/sanyo-ncr18650ga>`__.

*  `Polycarbonate tube, 11F (55in/141cm) <https://flowtoys.com/long-tubes-5f-to-13f>`__,
   1 inch outer diameter, from flowtoys.com. Note: while the tube is listed as 55",
   the actual length is 54.5".

*  1/2 inch (or 12 mm) square **wood dowel**, from
   `HomeDepot <https://www.homedepot.com/p/Waddell-1-2-in-x-36-in-American-Basswood-Square-Dowel-8308U/100547367>`__
   or any other hardware store. You need two  pieces, each at least 52 cm (slightly over 20").

Tools
-----
You will need the usual tools and supplies:

* wire strippers

* pliers

* flush cutters

* scissors

* decent soldering iron, solder, and flux

* heat gun

* hack saw

* electric tape, black, 3/4"

* fast-setting epoxy (I use `JB Weld Clearweld 5 minute epoxy <https://www.amazon.com/J-B-Weld-ClearWeld-Syringe-25mL/dp/B009EU5ZM0>`__)

* black spray paint

You will also need a computer with WiFi  to upload the images  and a charger
(either 5v charger with 5.5mm/2.1mm barrel jack connector, or a USB  charger and USB C cable) to charge the batteries.

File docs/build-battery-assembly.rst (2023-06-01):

Step 9: Battery and controller assembly
=======================================

1. Disconnect the batteries from the boards. Do not pull on the wires; instead, grab the
   plastic connector and pull it out (it takes some effort). Set the batteries
   aside for now.

2. Take the 3d printed spacers left in bag D. You should have one spacer that
   goes between the batteries, two spacers that go onto the ends of batteries, and 2
   small "plugs". Make sure you have them all.

3. Take QT Py microcontroller with the POV shield, a plug and one of end battery spacers.
   Assemble them together, putting the "plug" onto the board and then pushing
   the whole assembly into the spacer as shown below. Note: the "shelf" on the
   plug should be facing the white battery connector. Make sure to push it all the way in.

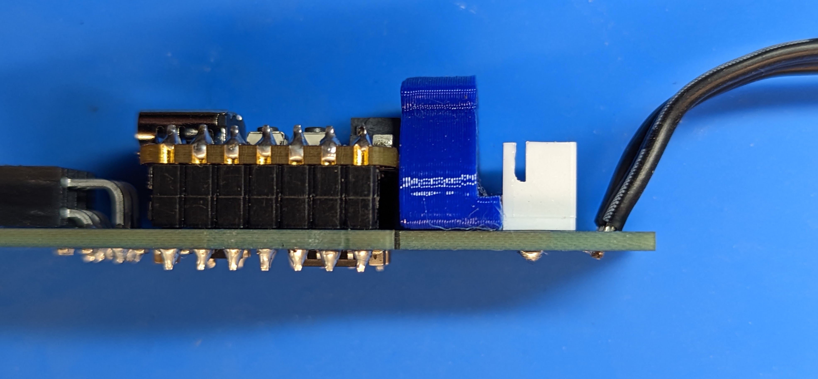
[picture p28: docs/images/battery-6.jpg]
Assembling the electronics and battery spacer
   

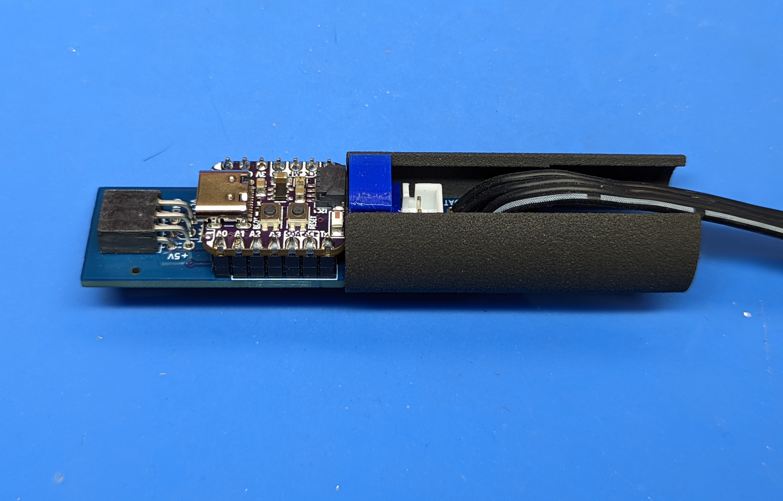
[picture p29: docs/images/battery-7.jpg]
Assembling the electronics and battery spacer
   

4. Repeat the same with the other spacer and plug and switch controller board.

5. Once you verified that everything fits, take it apart. Mix some epoxy glue
   and apply it to the outside of the plug (where it would be touching the inside
   of the spacer) and also on the bottom of the boards (again, where they would
   come in contact with the spacer). Assemble again; make sure the boards are
   fully inserted into the spacers and sit straight. If necessary, use electric
   tape or similar methods to keep the boards and plug in position.
   Put aside for one hour so
   that epoxy sets.

6. Once the epoxy sets,  insert the batteries (positive terminal first)
   into the spacers. Plug the
   battery leads into the connectors on boards. Carefully arrange the wires so
   that they run  along the battery through the openings in the spacers, with
   no wires crossing. Use 3/4" electric tape to attach the spacer to the battery,
   as shown below.  Make sure to apply the tape without any twists or kinks -
   otherwise, it will not fit into the tube. Do it with both batteries.

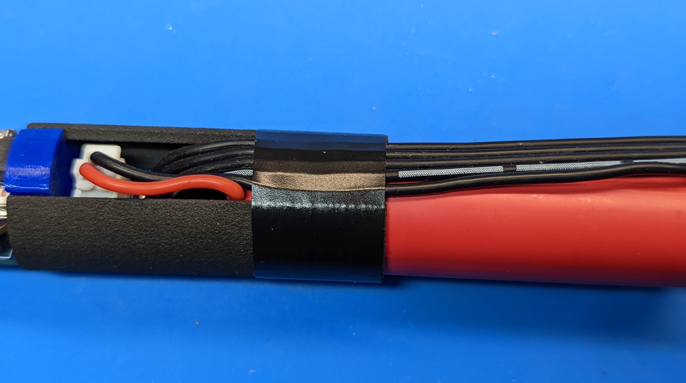
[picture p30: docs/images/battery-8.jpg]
Assembling the electronics and battery spacer
   

7. Finally, take mid-battery spacer. Insert the negative terminal of each battery
   into this spacer. **Warning**: only insert batteries from the end; do not try
   to force the batteries from top/bottom - you can break the spacer. Hide the
   slack of the wires into the spacer between the batteries, so the wires on
   the surface of the batteries is taut. Use electric tape to hold everything
   together as shown below.

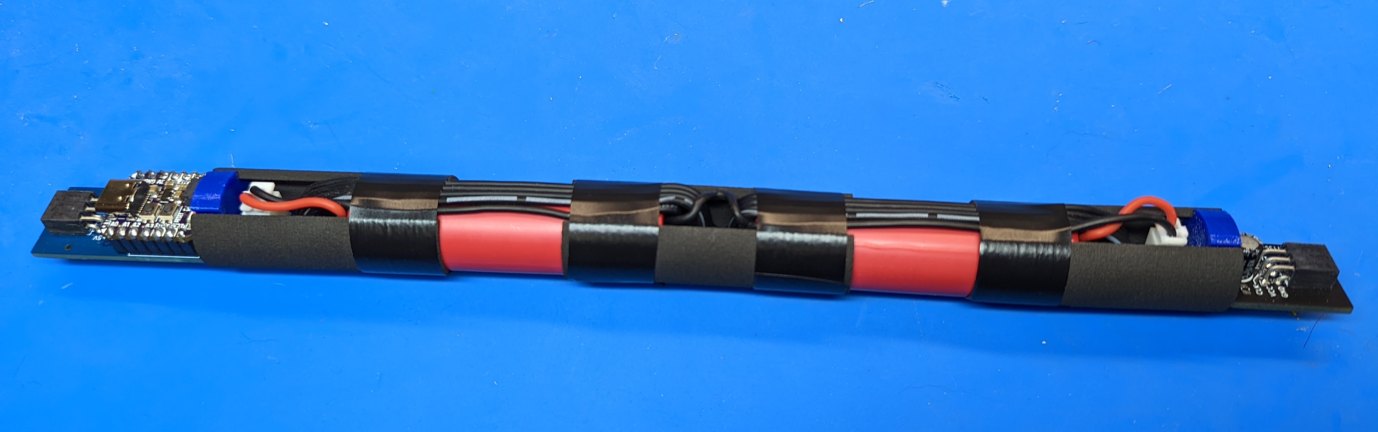
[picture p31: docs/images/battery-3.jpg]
Assembling the electronics and battery spacer
   

8. Try inserting the whole assembly into the tube. It should go in, possibley
   with some friction, but it shouldn't require force. If it doesn't go in easily,
   try to locate  the offending place (usually some slack in the wires or kink
   in the electric tape) and fix it.

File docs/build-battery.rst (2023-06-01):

Step 6: Batteries
=================
**Warning**: In this step, you will be soldering leads to Li-Ion batteries.
This could be dangerous if not done right! Please read all instructions
carefully and wear eye protection. You are working at your own risk!

**Materials and tools:**

* Bag D from the kit

  Kit of parts, bag D

  1. two 2-pin wires, with JST XH connector

  2. 3d printed spacer, to go between batteries

  3. Two 3d printed spacers to go at the ends of batteries

  4. 3d printed "plugs"

  5. 4-pin wire (22cm, 22AWG)

  6. Wire,  5.5 cm, 22 AWG

* Two 18650 Li-Ion batteries

**Steps:**

1. Find the two 2-pin wires with XH connectors. In each of them, cut the **red** wire to the
   length of 3.5 cm (not including the connector). Strip about 5mm of the red wire and tin.

2. Solder the red lead of the 2-pin wire connector to positive  (+)
   terminal of each battery. Follow instructions on `this page <https://oscarliang.com/solder-li-ion-battery-18650/>`__
   for soldering. Tip: an easy way to keep the battery vertical while soldering
   is by using the clamp as shown in the photo below.

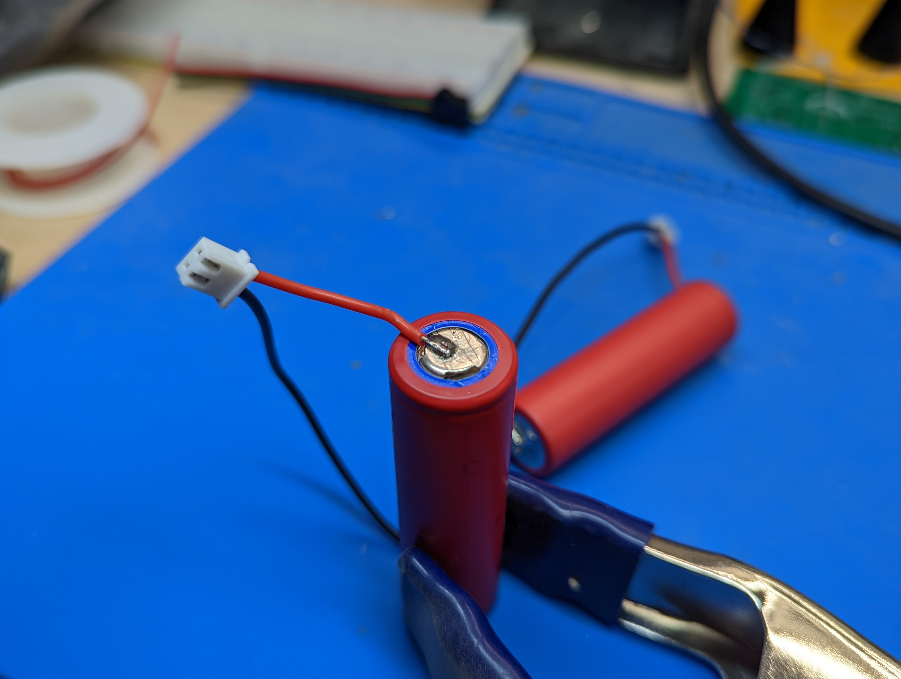
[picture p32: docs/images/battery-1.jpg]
Battery
   

3. Turn each of the batteries over, with the negative  terminal up. Solder the black lead to negative
   terminal.

4. Take the short black wire and solder  it to negative terminals of both
   batteries as shown below. Take care not to desolder the previously soldered wires.

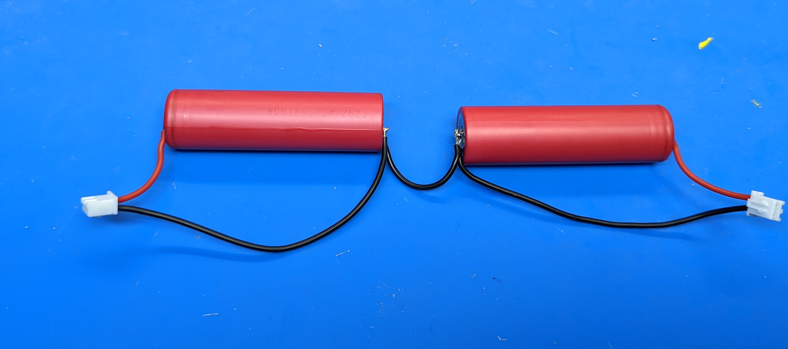
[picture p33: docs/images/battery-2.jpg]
Battery
   

 5. Use voltmeter to check the voltage difference between the positive terminals
    of the two batteries. If it is more than 0.1V, find a low ommage resistor
    (1 Ohm or about);  insert it into positive terminals of the two battery
    connectors and leave for an hour to equalize the voltage.

Bag D also contains 3d printed spacers and 4-pin wire; they  will be used in
the following  steps.

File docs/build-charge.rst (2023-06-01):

Step 3: Charge connector
========================
**Materials and tools:**

* Bag B from the kit

  Kit of parts, bag B

  1. Charge connector

  2. 3d printed housing for charge connector

  3. 2-pin wire (55 cm, 24 AWG)

  4. Charging adapter (USB C to 5.5mm barrel jack)

* flush cutters, soldering iron

**Steps:**

1. Take the two-pin wire from bag B. Insert the ends of the wire into holes
   in the charge connector contacts as shown below.
   **Important**: the wire with white stripe should be soldered to the shorter
   contact  (this goes to the center pin, which is the positive contact).

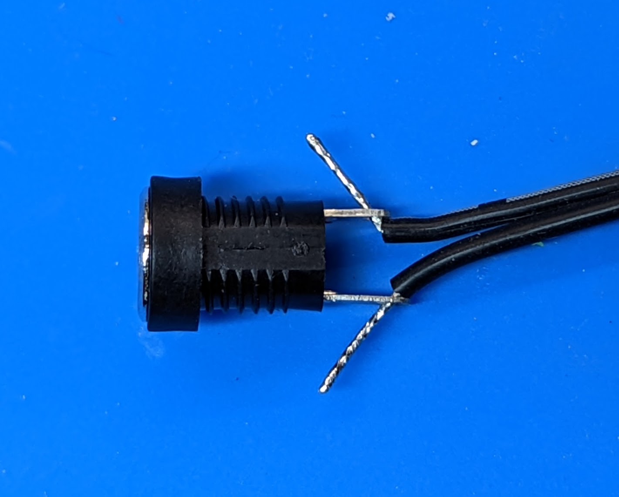
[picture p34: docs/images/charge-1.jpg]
   

2. Solder the wires. Use flush cutters to trim the soldered wires.

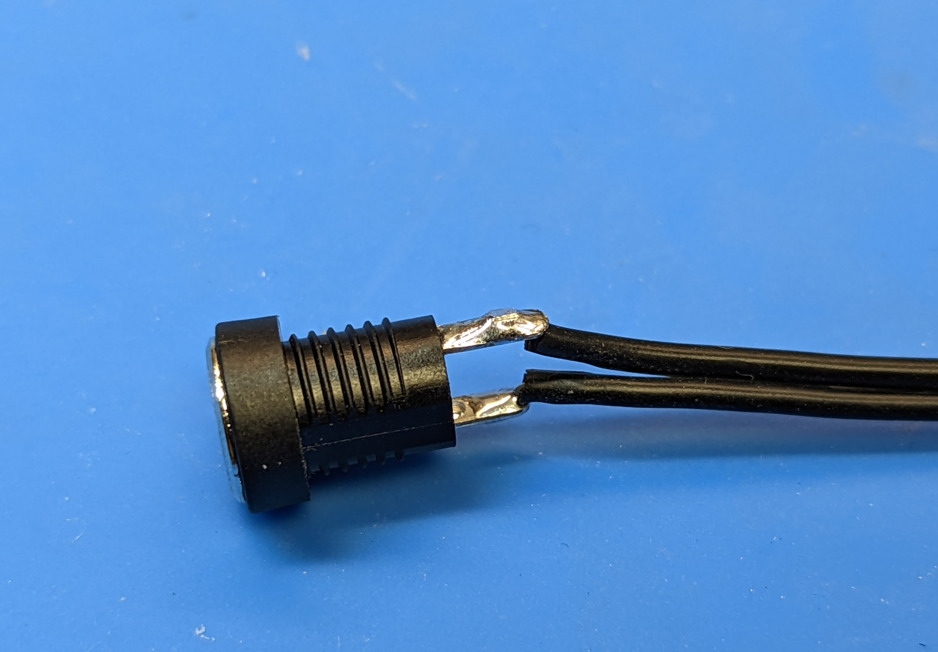
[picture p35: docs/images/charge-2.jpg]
   

3. Insert the charge connector in the 3d printed spacer as shown below. Push
   against  a flat surface (e.g. the table) to make sure it is all the way in.

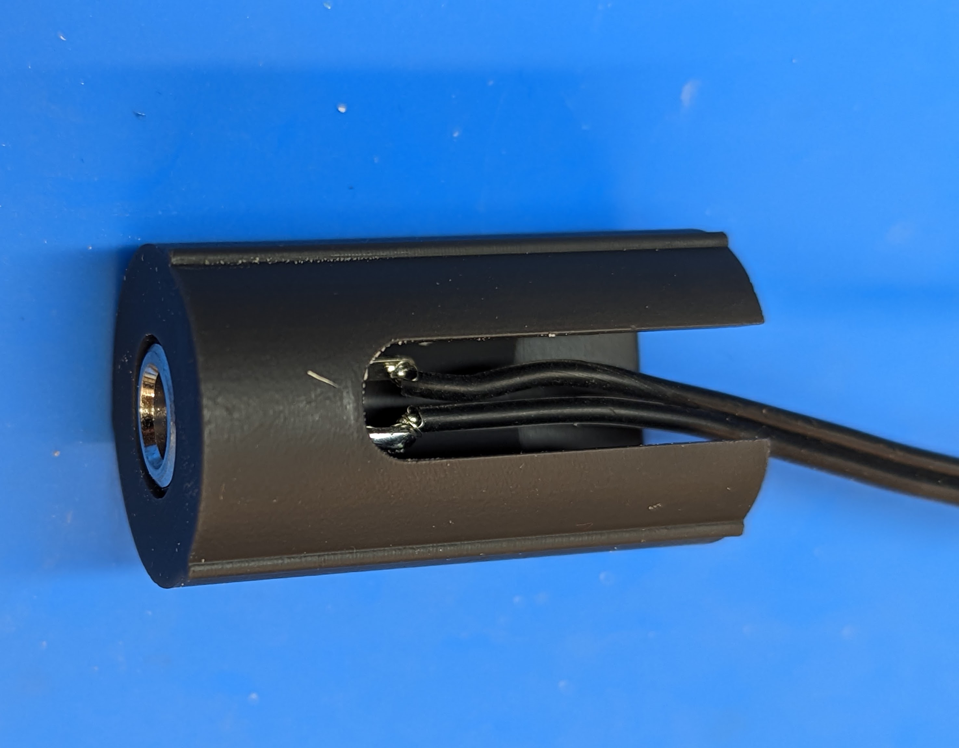
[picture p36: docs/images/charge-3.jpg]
   

4. Take the LED assemblies created previously. Select the one with PDB labeled
   "CHARGE" (blue PDB). **Important: make sure you got the correct assembly!**
   Put the 3d printed spacer with charge connector onto the
   other end of the dowel, making sure that the opening in the spacer is on the
   same side of the dowel as the two holes in the PDB.

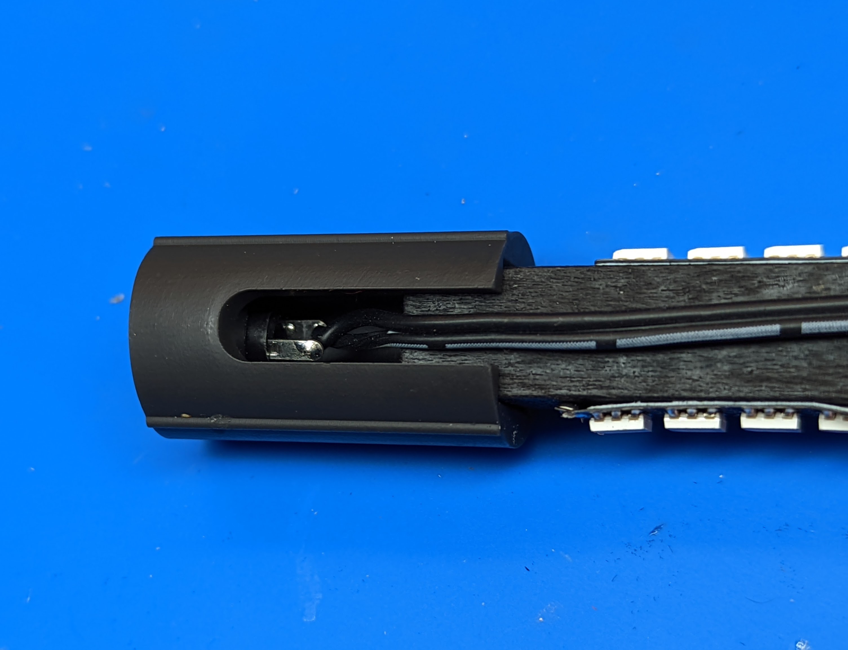
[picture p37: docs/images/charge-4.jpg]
   

5. Run the wire along the wood dowel; straighten it to remove twists. Insert the
   tinned ends of the wire into the holes in the PDB. **The wire with white stripe
   should go into the hole labeled "5V".** Solder the wire and then trim the
   wire ends protruding on the other side.

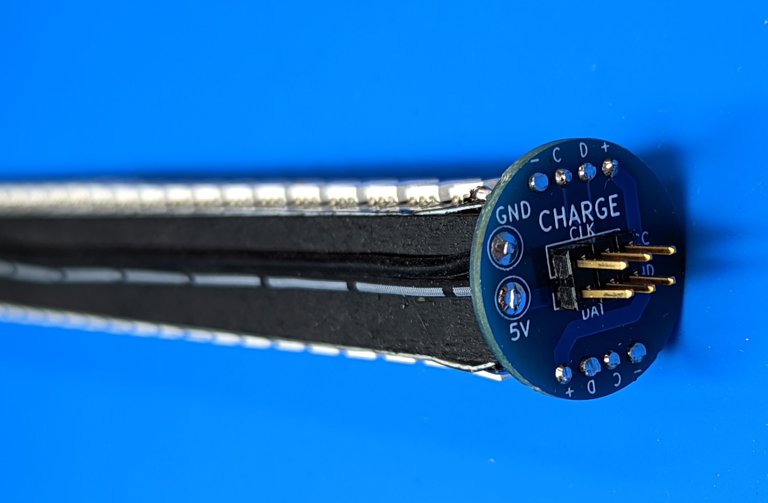
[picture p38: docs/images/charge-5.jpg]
   

Bag B also contains the charge adapter - keep it to use when charging the staff.

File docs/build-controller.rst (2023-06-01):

Step 7: Controller assembly
===========================
Materials

* Bag E from the kit

  Kit of parts, bag E

  1. QT Py ESP32-S3 MCU, preprogrammed

  2. Custom-made POV controller board (blue), containing Inertial Motion Unit, battery
     charge circuit, and more.

  3. Switch  connector board (black)

  4. Two 7-pin headers

* 4-pin wire, left over from the previous step

**Steps:**

1. Before doing any work, get  the  ESP32-S2 Qt Py
   microcontroller from the bag and  test it. To do that, connect it by USB
   cable to a computer or
   charger to power it up. The on-board NeoPixel LED should blink red, then
   yellow, then turn green.  **Wait  for 20-30 seconds** and open  the WiFi
   connection dialog of your computer. You
   should see there a new WiFi network with the name `POVSTAFFXXXX`, where XXXX
   will be replaced by a 4-digit number, unique for each staff. Connect to this
   network; the password is in the information sheet
   which was included with your kit -  if you misplaced it,
   email `irobotics.store@gmail.com` for help.
   Type the following address in the URL field of the browser: `http://povstaff.local:8080`
   (note: the staff doesn't support https protocol. If your browser gives you a
   warning about unsecure connection, click on "continue to site".)
   You should see the webpage of the staff, which looks as follows:

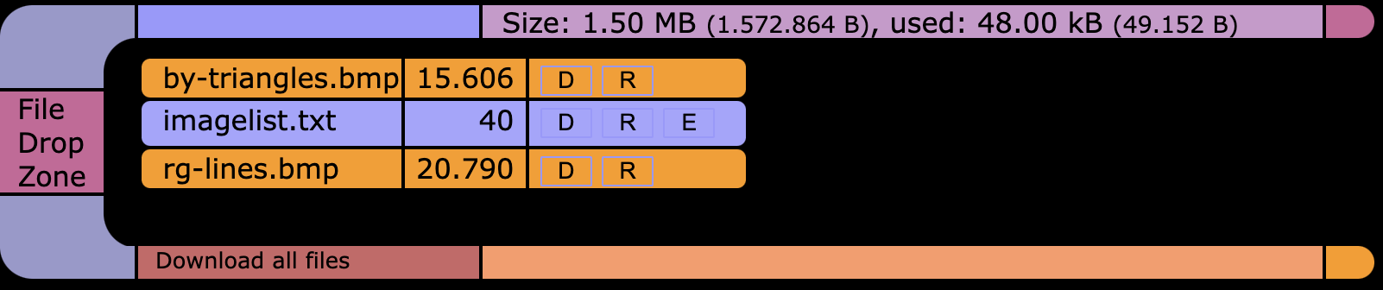
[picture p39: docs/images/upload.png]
Upload web page
   

   If you see the files `imagelist.txt`, `rg-lines.bmp` and `bg-triangles.bmp`,
   everything is good - you can disconnect the USB cable and proceed. Otherwise,
   check the troubleshooting section.

2. Solder the headers to the custom  POV controller shield as shown below.
   **Make sure to solder it on the correct side of the board.**  The easiest way
   to keep the headers straight while soldering is to plug them into a breadboard.

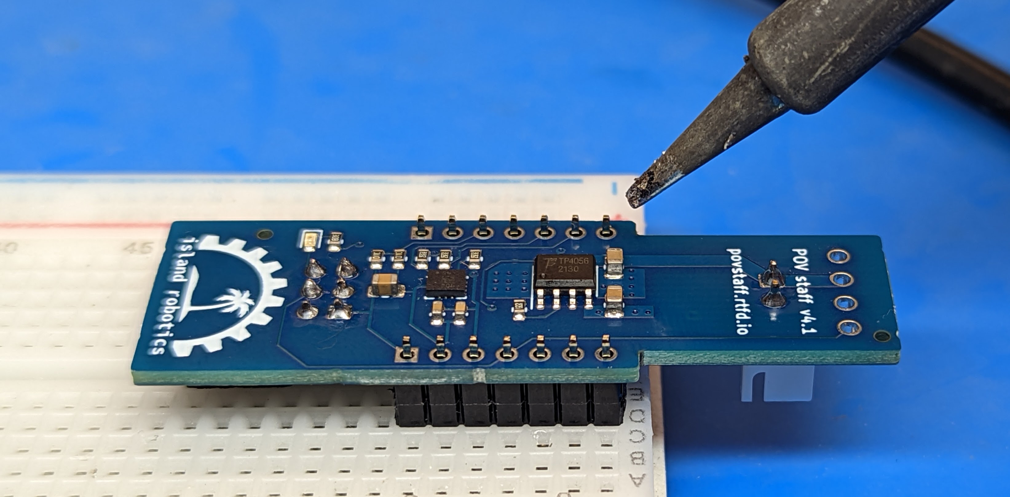
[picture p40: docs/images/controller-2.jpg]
Soldering headers to POV controller shield
   

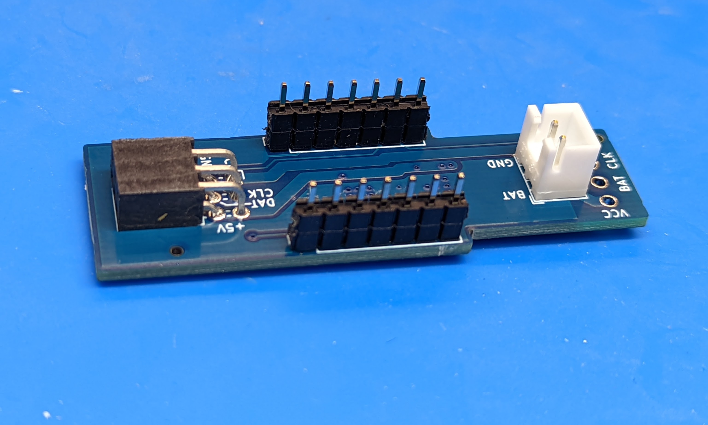
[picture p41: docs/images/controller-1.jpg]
Soldering headers to POV controller shield
   

3. Solder the ESP32-S2 QT Py  board to the headers, forming a "sandwich" of two boards
   as shown in the photos below. Make sure to solder it in the correct orientation:
   the USB connector should be on top and facing the same way as the black 6-pin header on
   the controller shield.

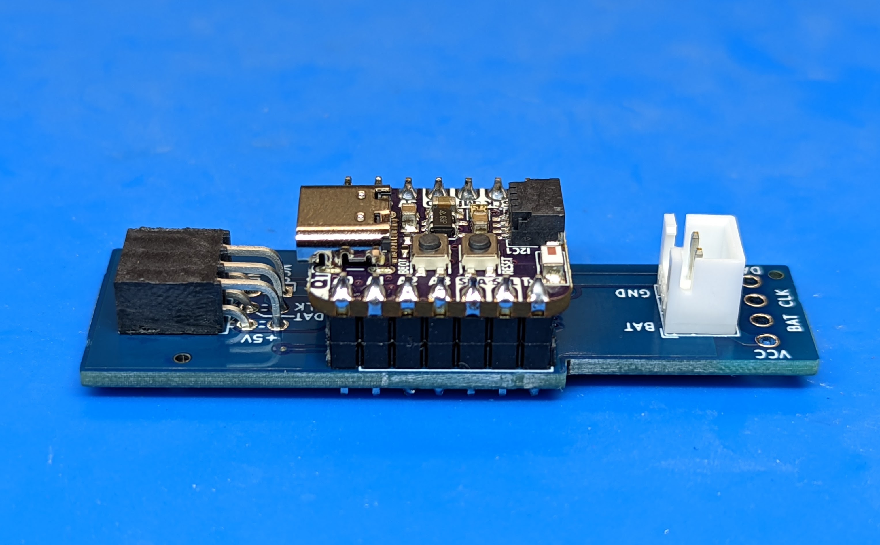
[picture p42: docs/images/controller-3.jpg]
Controller with shield
   

4. Take the 4-pin wire left over from the previous step and solder it to the
   controller board on one side and to
   the switch connector board on the other as shown below. On each board, the
   **wire with white stripe should go into the hole labeled "VCC"**.

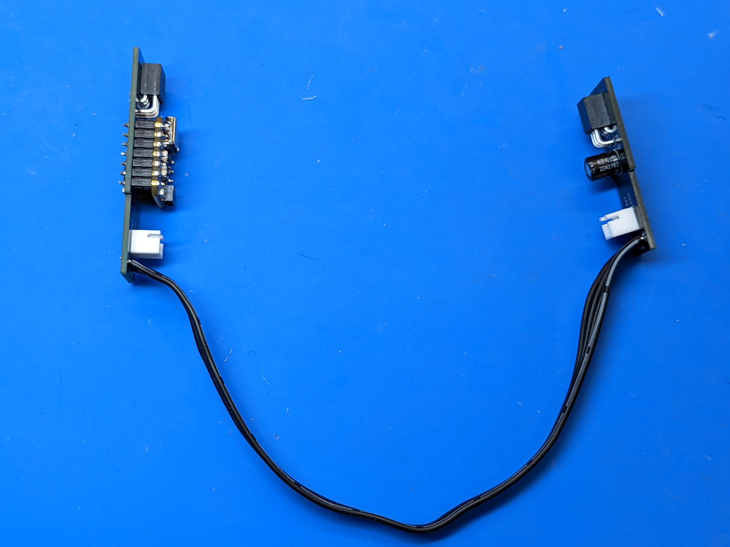
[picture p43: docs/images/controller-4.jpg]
Controller, shield and wire


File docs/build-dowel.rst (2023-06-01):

Step 1: Dowels
===============

**Materials:**

* two 1/2" square wood dowels

* Bag A from the kit

  Kit of parts

  1. two power distribution boards (PDB),

  2. two  2x3 pin headers (to be soldered to the PDBs)

  3. 22AWG solid core wire (to be soldered to LED strips)

  4.  3d printed press tool, to be used for pressing hte PDBs into the dowels. Discard after use

  Note: color of the wire and press tool may vary.

* Spray paint, epoxy resin.

**Steps:**

1. Take the two  1/2" square wood dowels. Use hacksaw to cut each of them to **51.9 cm**
   length; try to keep the cuts square.

2. Spray paint each of them black. Let dry (you can work on the other steps
   while the dowels are drying).

3. Solder the 2x3 header to each PDB. Make sure to solder it on the correct side:
   the plastic spacer should be on the side labeled CHARGE (or SWITCH)

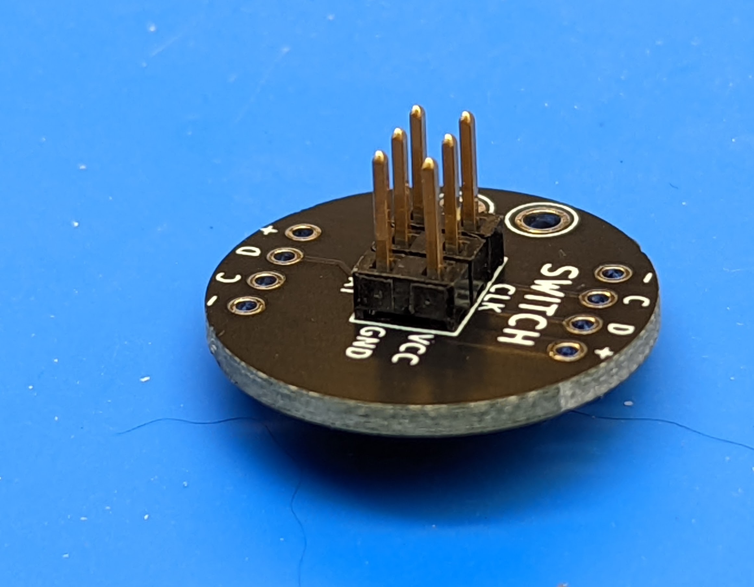
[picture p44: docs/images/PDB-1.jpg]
PDB with header
   

4. Use flush cutters to trim the 4 corner metal pins on the back side of each PDB,
   leaving the two middle ones intact:

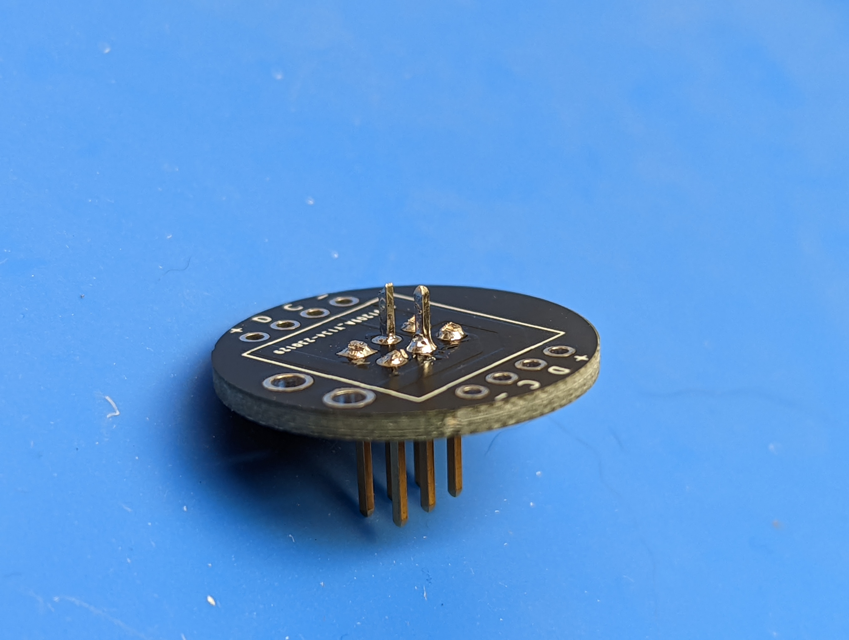
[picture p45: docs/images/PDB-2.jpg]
   

5. Use the flush cutters to cut about 1 mm off the tip of the two remaining pins on the back
   at 45 degree angle,  creating sharp points.

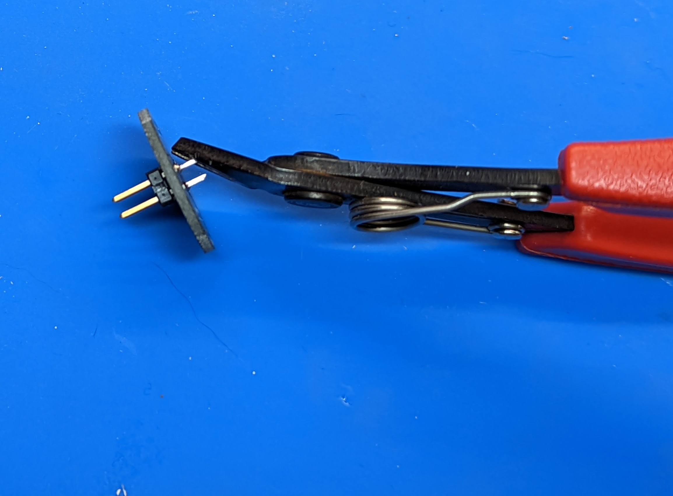
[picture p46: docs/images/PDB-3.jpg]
   

6. Press the  PDB with soldered headers  into the end of the dowel. Use the
   square drawing on the back for alignment with the dowel. To avoid damaging the
   header pins, use the included 3d-printed press tool: place it on the table,
   then the PDB on it (face down), then press the dowel into it. Make sure to
   press it all the way in: there should be no gap between the dowel and the PDB.
   Repeat  with the other dowel and power distribution board.

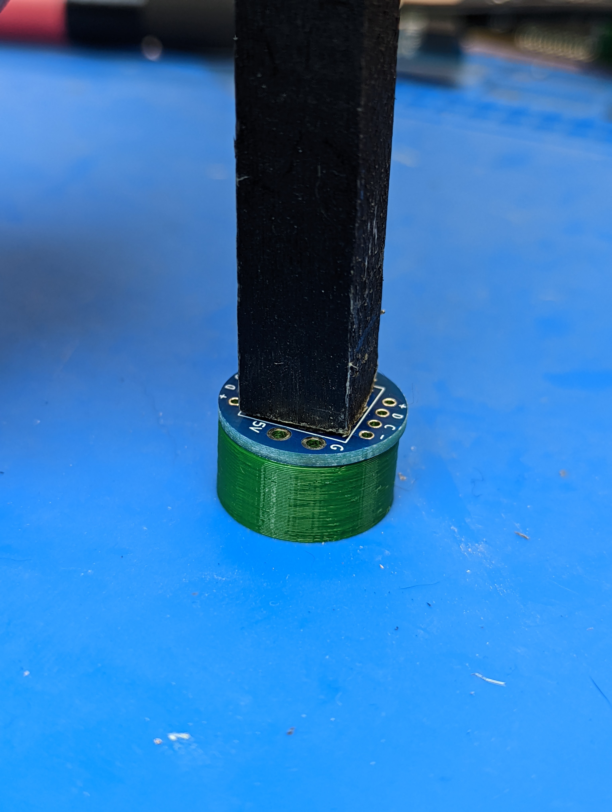
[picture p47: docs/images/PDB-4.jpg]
Dowel with PDB
   

7. Remove the PDB from the dowel. Mix some epoxy glue, apply it to the end of
   the dowel and replace the PDB seating it fully. Repeat with the second PDB
   and dowel. Be careful that no epoxy gets on the holes for wires.
   Leave for an  hour to let the epoxy set.

After completing this step, you can discard the 3d printed press tool - you won't
need it any longer.

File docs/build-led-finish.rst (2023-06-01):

Step 5: Finishing LED assemblies
======================

1. Mix some epoxy resin.

2. Take the two LED assemblies created in the previous steps. Peel off about
   1 cm of the LED strip (from the end farthest from the PDB), add epoxy
   underneath and put back. Repeat with all 4 LED strips. Use zipties to hold
   LED strips in place while the epoxy sets.

3. Straighten the wires that go from switch and charge connector to PDBs; push
   any slack inside the 3d printed spacer so that the part of the wire running
   along the dowel is taut. Add epoxy in 2-3 places  along the dowel to attach
   the wire to the dowel. Again, use zipties to hold wire in place.

4. Leave the LED assemblies aside for an hour until epoxy sets. After that,
   remove and discard the zipties.

This completes the construction of two LED assemblies.

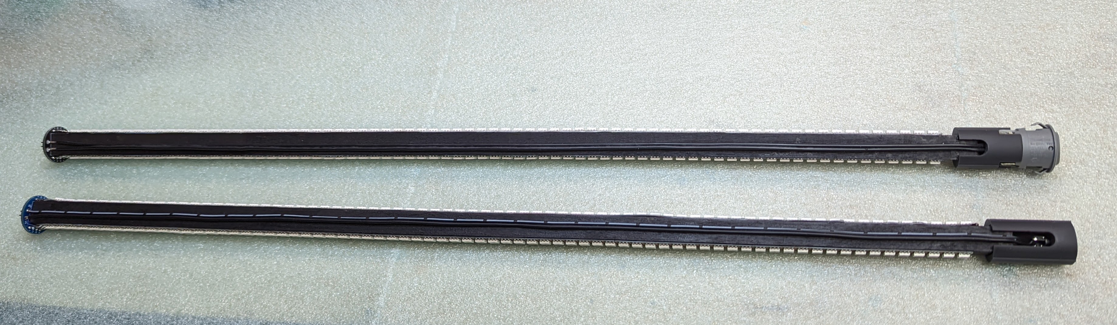
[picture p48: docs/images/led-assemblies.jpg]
LED assemblies


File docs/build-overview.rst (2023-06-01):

Build overview
==============
The staff consists of the following subassemblies:

* **battery assembly**, containing two batteries, controller board,  wiring, and spacers. This
  assembly is placed in the center of the staff

  Battery assembly

* two **LED assemblies**, one on each side of the battery assembly. Each LED
  assembly consists  of the wood dowel with two 50cm LED strips on opposite sides
  of the dowel. On inner end of the dowel, there is a power distribution board (PDB)
  to which both LED strips are connected; on the outer, one assembly has a
  charging connector, and the other, a switch.

  LED assemblies

All of the above are inserted into the **polycarbonate tube** and protected at both ends
by 3d printed endcaps wrapped in soft foam. The middle of the tube is wrapped
in tennis racket  **grip tape** to provide secure grip.

**Warning**:

1. At some steps you will be using  epoxy. Please be careful that it
   doesn't get on your skin - to be on the safe side, you can  put on thin
   latex  gloves.

2. You will be soldering leads to 18650 Li-Ion battery. It can be dangerous if
   not done right. Make sure to **carefully read the instructions** before doing this. If you
   are not sure you can do it, then this project is not for you.

If you messed up, destroying one of the parts, or misplaced it, do not worry!
Email me at irobotics.store@gmail.com and I can send you a replacement.

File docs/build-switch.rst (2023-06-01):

Step 4: Switch connector
========================
Materials and tools:

* Bag C from the kit

  Kit of parts, bag C

  1. Switch

  2. 3d printed housing for the switch

  3. 2-pin wire (55cm, 20 AWG)

* flush cutters, soldering iron

**Steps:**

1. Take the two-pin wire from bag C. Insert the ends of the wire into holes
   in the switch terminals  as shown below. Note: one of the wires
   must be soldered to the **middle** terminal, and the other,
   to one of the other terminals (doesn't matter which one). It doesn't matter
   which of the two wires is soldered to the middle terminal.

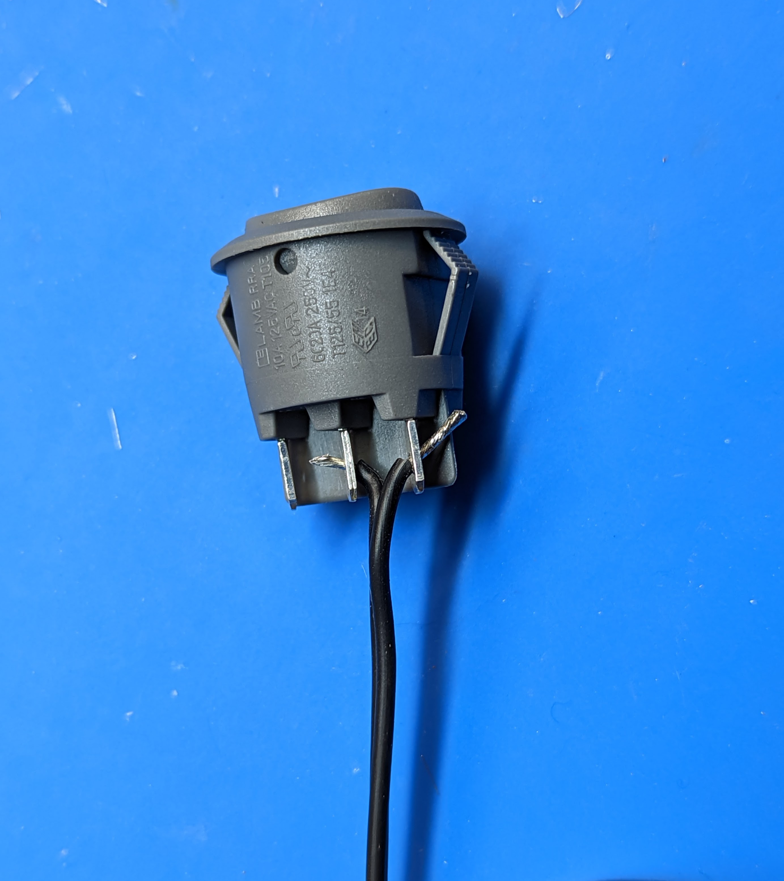
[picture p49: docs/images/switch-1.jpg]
Switch
   

2.  Solder the wires. Use flush cutters to trim the protruding end of the wires.

3. Using flush cutters, cut open the plastic retention tabs on both sides of
   the switch as shown below. Note: it is recommended to cut it below the "joint".

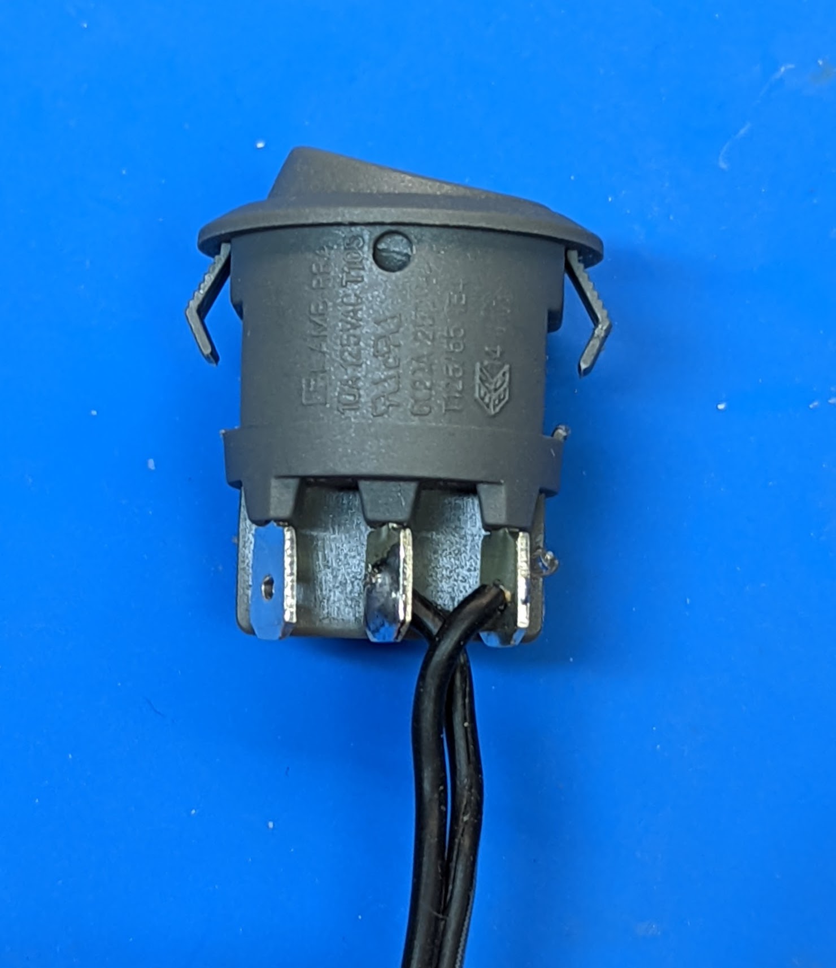
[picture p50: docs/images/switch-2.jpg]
Switch
   

4. Insert the switch in the 3d printed spacer as shown below.

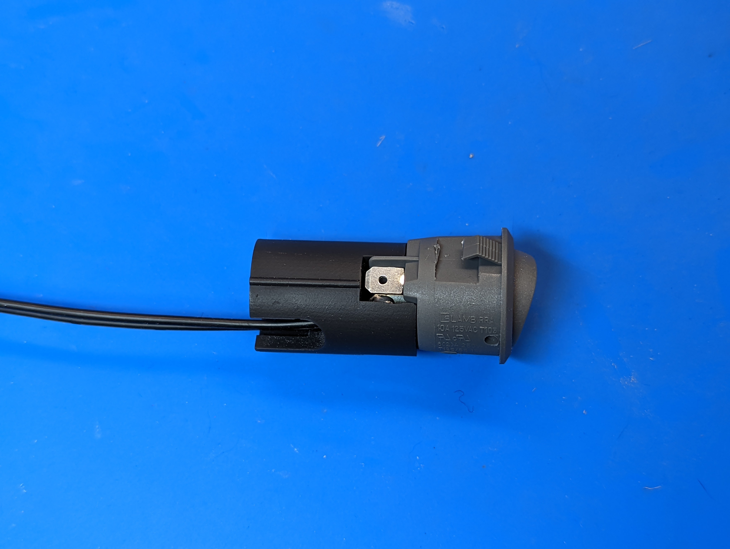
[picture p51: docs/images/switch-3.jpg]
Switch
   

5. Take the remaining ("SWITCH") LED assembly, with black PDB.
   Put the 3d printed spacer with the switch  onto the
   other end of the dowel, making sure that the opening in the spacer is on the
   same side of the dowel as the two holes in the PDB.

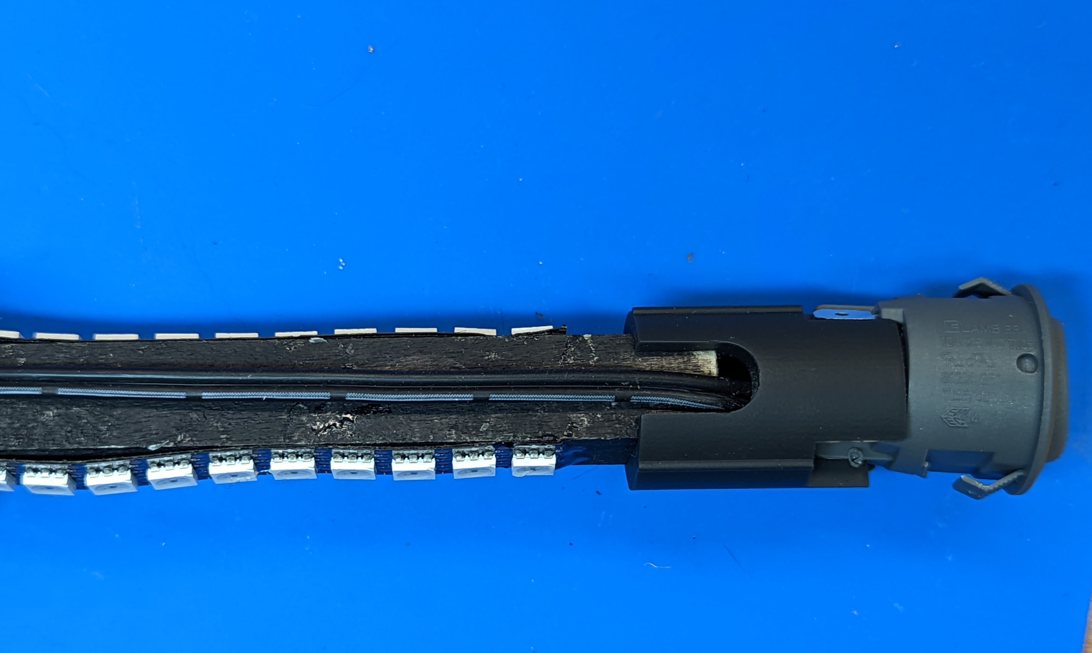
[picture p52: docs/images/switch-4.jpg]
Switch
  

6. Run the wire along the wood dowel; straighten it to remove twists. Insert the
   tinned ends of the wire into the holes in the PDB. It doesn't matter which
   wire goes into which hole. Solder the wires and use flush cutters to trim the
   wire ends protruding from  on the opposite side of the PDB.

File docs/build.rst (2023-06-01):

.. _build:
**************************
Build Guide
**************************

Please follow the steps below to build your staff.

.. toctree::
    :caption: Table of Contents
    :maxdepth: 1

    build-materials
    build-kit
    build-overview
    build-dowel
    build-led
    build-charge
    build-switch
    build-led-finish
    build-battery
    build-controller
    build-testing
    build-battery-assembly
    build-final

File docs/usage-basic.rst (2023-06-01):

Basic usage
===========
To **turn the staff on and off**, use the switch at one end of the staff. It is a
3-position switch;  middle position is always OFF; one of the two other
positions is ON.

As soon as you have turned the staff on, it will show the battery voltage, by
lighting part of the LED strips. The longer the strip, the higher the battery charge.

If you only see one or two LEDs light up, the battery charge is too low for
use. You need to recharge the batteries as described in the next section.

After using the staff, **make sure to turn it off**! If left on, LEDs will
drain the battery rather fast - even if you are not using the staff. To remind
you to turn it off, the staff will be blinking  red LEDs once every 30 seconds
while it is on and not being used.

To **start the show**,  turn the staff ON and start spinning it.
The staff will begin showing your first image, one line at a time,
and will continue doing that as long as you are twirling the staff. It will
adjust the interval between successive lines depending on the rotation speed,
to keep the image ratio close to original regardless of how fast you are
rotating the staff.

You can find a number of staff spinning tutorials on YouTube - just search for
"staff spinning tutorials for beginners". I learned a lot from these two:
https://www.youtube.com/watch?v=L0madJzk3Wc and
https://www.youtube.com/watch?v=gm5D8TS3mNY.

The staff will continue showing the image for the duration given in
`imagelist.txt` file or until you pause the staff as described below, whatever
comes first. If duration for a given image was not provided, the staff will
continue showing this image until you pause.

To **pause** the show or move to the next image in the list, stop the staff
**in vertical position**. It will go blank; as soon as you start spinning it
again, it will resume the show, moving to the next image. After reaching the
last image in the list, it will loop over, starting again with the first image.

After you are done, do not forget to **turn the staff OFF**, to avoid draining
the batteries.

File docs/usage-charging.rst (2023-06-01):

Charging
===========
To charge the staff, turn it off by setting the switch in the OFF position.
You can charge using one of the following methods.

* Use a 5V power supply with 5.5mm OD/2.1mm ID barrel jack (center pin positive).
  Plug it into the connector at the charging end of the staff (opposite the switch).

* Alternatively, use the included USB C to 5.5mm barrel jack adapter and a USB C cable, plugged into a USB charger.
  Note: if using a USB C to USB C cable, many "smart" chargers (e.g. Apple macbook charger) will refuse to charge the staff as they require the connected device  to identify its capabilities. To avoid this problem, use a USB C to USB A cable.

Full charge should take about 5 hrs.

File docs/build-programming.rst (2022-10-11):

Step 7: Uploading firmware
===============================

If you are using a kit from our Tindie store which included ItsyBitsy M4 MCU, you can skip
this step - the MCU comes already pre-programmed.

Using precomplied binaries (M4 only)
------------------------------------
The easiest way to program the controller is by   using pre-built
binaries (for Itsy Bitsy M4 only).

1. Download the latest release of the project from |github|.
   Extract the downloaded archive to some place on your computer, and navigate to
   directory `code/binaries/ItsyBitsyM4`.

2. Connect the controller assembly to your computer using a micro USB cable. If
   you are doing it for the first time, you might get a message about
   installing drivers; in this case, wait until it tells you that your hardware
   is ready to use. Double-click the reset button on ItsyBitsy; your ItsyBitsy
   should appear as an external drive on your computer, with a name like `ITSYM4BOOT`.
   Open that drive in your file browser window; inside you should see files
   `CURRENT.UF2`, `INDEX.HTM`, and `UF2_INFO.TXT`.

3. First, you need to format the flash storage on ItsyBitsy board as FAT filesystem;
   you only need to do that once. To do that, inside extracted  directory `code/binaries/ItsyBitsyM4`, find the file
   `formatter.UF2` and drag and drop it to `ITSYM4BOOT`.  If you get a question
   "do you want to copy this file without its properties", click "Yes".
   After that, the ItsyBitsy will reboot, `ITSYM4BOOT` will disappear from your
   computer, and the formatter script will run; you won't see any visible output.

4. Double-click the reset button on ItsyBitsy again; `ITSYM4BOOT` drive should
   again appear on your computer. This time, drag `povstaff-vX.X.UF2` file to it.
   Again, the ItsyBitsy will reboot. The microcontroller now contains
   the povstaff software.

5. Press `Reset` button once (or disconnect and reconnect the USB cable) to restart
   the ItsyBitsy. It should now appear as an external drive with the name
   `POVSTAFF` in your computer, which should be empty.  Find in the extracted
   archive folder `images` and drag and drop files `rg-lines.bmp` and
   `imagelist.txt` to `POVSTAFF`. Eject the `POVSTAFF` drive and disconnect
   the USB cable; it is now ready for use.

Building from source
---------------------
An alternative way to program the controller is by building the software from
source. You will need Arduino IDE 1.8 or later to do that. It is assumed that
you have some experience with Arduino, e.g. know how to install libraries using
library manager.

1. Start Arduino IDE and install the board support files for your Itsy Bitsy (see instructions for
   `M4 <https://learn.adafruit.com/introducing-adafruit-itsybitsy-m4/setup>`__,
   `nRF52840 <https://learn.adafruit.com/adafruit-itsybitsy-nrf52840-express/arduino-support-setup>`__).

2. Make sure that you have the following libraries installed. All of them can
   be installed using library manager:

   *  FastLED
   *  Adafruit_TinyUSB
   *  Adafruit_SPIFlash
   *  Sd_Fat (adafruit fork)
   *  Adafruit_Sensor
   *  Adafruit_MPU6050
   *  POV-library

3. Connect the ItsyBitsy MCU to the computer using a microUSB cable.
   In `Tools` menu of Arduino IDE, select the correct board and port.
   Also, if using  Itsy Bitsy M4, select `Tools->USB stack->TinyUSB`.

4. First, you
   need to format the QSPI flash storage included on the board. To do so, find
   in the menu `File->Examples->Adafruit SPIFlash->SdFat_format`. Edit the line

   .. code-block:: C

      #define DISK_LABEL    "EXT FLASH"

   replacing `EXT FLASH` by a label of your choice, up to 11 symbols (e.g. "POVSTAFF").
   Upload the sketch to your board and start the serial monitor at 115200 baud.
   You should see a message asking you to confirm reformatting; respond "OK" to
   confirm and you should see message "Formatted flash".

5. Now, you are ready to upload the POV firmware.
   Download the latest release of POV staff project from |github| if you
   haven't done so already. Extract the archive file and find there folder
   `code/povstaff`. Copy the `povstaff` folder to your Arduino sketch folder.
   Open the sketch file `povstaff.ino` inside `povstaff` folder in Arduino IDE.

6. Click `Upload` to compile and upload the code. It can take  a while (mostly
   due to use of FastLED, which is a massive library). Once you get the message
   `Done uploading`, the programming is complete.

7. Press `Reset` button once (or disconnect and reconnect the USB cable) to restart
   the ItsyBitsy. It should now appear as an external drive with the name
   `POVSTAFF` (or whatever name you have chosen in step 4) in your computer,
   which should be empty.  Find in the extracted
   archive folder `images` and drag and drop files `rg-lines.bmp` and
   `imagelist.txt` to `POVSTAFF`. Eject the `POVSTAFF` drive and disconnect
   the USB cable; it is now ready for use.

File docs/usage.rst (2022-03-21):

**************************
User Guide
**************************

.. toctree::
    :caption: Table of Contents
    :maxdepth: 1

    usage-basic
    usage-charging
    usage-upload

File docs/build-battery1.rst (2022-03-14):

Step 1: Battery assembly
==========================
**Warning**: In this step, you will be soldering leads to Li-Ion batteries.
This could be dangerous if not done right! Please read all instructions
carefully and wear eye protection. You are working at your own risk!

Materials and tools used:

* Two 18650 Li-Ion batteries

* Two battery  wire harnesses

* Spacers

* Shrink wrap (from kit of parts)

* Soldering Iron, solder, flux

1. Find the first battery wire harness (28cm, 4 wire). Put one piece of the
   8mm diameter shrink wrap on one end of the harness (note: **do not** shrink
   it). Now, insert the 4 tinned ends of the wire harness into the holes of the
   PDB as shown  below. You must be inserting from the side with label **PDB-A**
   (or **PDB-B**). The wire with white stripe should go into the hole next to +
   sign as shown in the photo below.

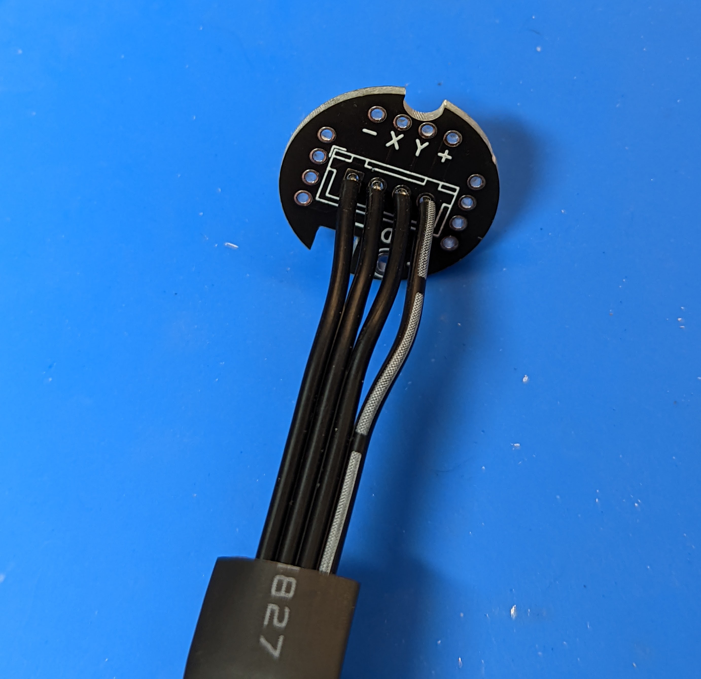
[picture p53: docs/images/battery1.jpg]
   

    Solder the wires from the opposite side. Use flush cutters to trim
    protruding wires, **leaving about 2mm**.

   Soldering PDB

1. Solder the two wire leads from the black battery wire harness to negative (-)
   terminal of each battery. Follow instructions on `this page <https://oscarliang.com/solder-li-ion-battery-18650/>`__
   for soldering. Tip: an easy way to keep the battery vertical while soldering
   is by using the clamp as shown in the photo below.

Battery

Battery

2. Turn the batteries over, with the positive terminal up. Use voltmeter to
   check the voltage difference between the positive terminals of the two batteries.
   If it is more than 0.1V, find a low ommage resistor (1 Ohm or about);  press and hold
   it against the two positive terminals, to equalize the voltage.

3. Take the red wire harness from the kit of parts and solder the two red leads
   to positive terminals of the batteries. Make sure the direction they are
   pointing is same as direction the black leads on the negative terminal.

Battery

4. Arrange the two batteries in line, placing the spacer between. (Use the
   spacer with partly covered top and bottom). Carefully straighten the wires
   along the surface of the batteries, making sure they do not cross. Use electric
   tape to hold them. Make sure that the bullet point connectors reach  at least
   3.5cm beyond the end of the battery on each side.

Battery

5. Take the piece of the large diameter shrink wrap and put it over the middle
   section of battery assembly. Push the batteries and spacer tightly together,
   being careful not to pinch any wires. Use the heat gun at low temperature
   setting  to shrink the wrap.

Battery

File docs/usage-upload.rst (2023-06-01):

Uploading new images
====================

Finding images
--------------
You can use any image satisfying the following requirements:

* Images must be in bitmap (BMP) format, with 24 bit color depth. Use any
  software you like to convert images in other formats to bmp - e.g. you can use
  Microsoft Paint 3D.

* The images are shown one **horizontal** line at a time; thus,  it is
  recommended to use images with **width** of 72 pixels - to match the number
  of LEDs on the staff. Maximal image size is 72x288 pixels.

* Image filenames must be at most 30 symbols long and can only contain letters,
  numbers, dashes and underscores. No spaces or special symbols!

You can create your own images or search for existing ones.  A good source for
POV image patterns is `Visual  POI Zone <https://visualpoi.zone/patterns/>`__.
When downloading images from there, make sure to choose `Visual poi V4 mini (72px)`
option. You will also need to rotate images 90 degrees.

Please note that the same color (i.e. the same RGB values) can look quite
different on the screen of your computer and on LED strip. Experiment with
colors to get some feel for it.

To help you figure out correct rotation and orientation of images, the pictures
below show the same image in BMP file and how it will look when using the POV staff.

Image in file

Image on staff

Directory `images` in the GitHub repository https://github.com/shurik179/povstaff
contains some sample images and `imagelist.txt` file. These images have already been
uploaded to the staff.

Creating imagelist file
-----------------------

Once you have found or created your own images, move them all to the same folder
on your computer.

Now,  you need to create a list showing in which
order these images should be played during the show. Create the file
`imagelist.txt` in the same folder as the images  (or open the file if
it already exists) and put there the list of image files in the order you want
to use them in your show, one filename per line. Include the  `.bmp` extension
in each filename, and put leading slash (/) before each filename, as shown below.
Optionally, you can also add how long the image should be shown, in seconds
(whole numbers only!), separated from  filename by one or more spaces:

.. code-block:: python

   /image1.bmp 20
   /image2.bmp 41
   /image5.bmp 10
   /image1.bmp

You can include some image file more than once, or not at all - it is your
choice. The name of your image list must be `imagelist.txt`, all lower case.

Uploading images
-----------------

To upload images, place the staff on a horizontal surface (e.g. on the floor)
and turn it on. It will briefly light up to show the battery voltage and then
go into upload mode; to indicate that, every 4th LED should be lighted in light
green color.

Wait for 20-30 seconds and open  the WiFi search dialog of your computer. You
should see there a new WiFi network with the name `POVSTAFFXXXX`, where XXXX
will be replaced by a 4-digit number, unique for each staff. Connect to this
network, using the password which you can find in the information sheet
included with your kit; if you misplaced it,
email `irobotics.store@gmail.com` for help.

Type the following address in the URL field of the browser: `http://povstaff.local:8080`
(note: the staff doesn't support https protocol. If your browser gives you a
warning about unsecure connection, click on "continue to site".)
You should see the webpage of the staff, which looks as follows:

Upload web page

Drag and drop the image files and the imagelist.txt file to the `file drop area`
area of the webpage.

You can delete files you no longer need by pressing on  letter 'D' next to the
filename. You can also edit imagelist.txt file online by clicking on  'E'.

Once the files have been uploaded, just turn the staff off.

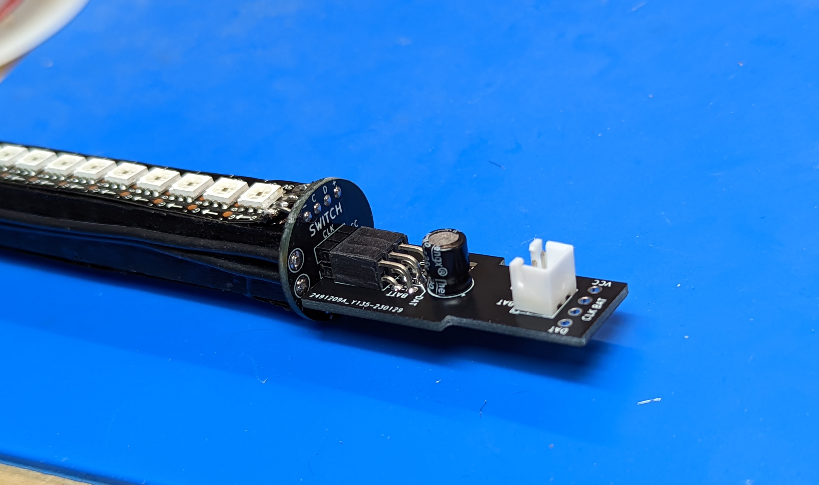
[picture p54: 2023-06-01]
docs/images/assembly-1.jpg

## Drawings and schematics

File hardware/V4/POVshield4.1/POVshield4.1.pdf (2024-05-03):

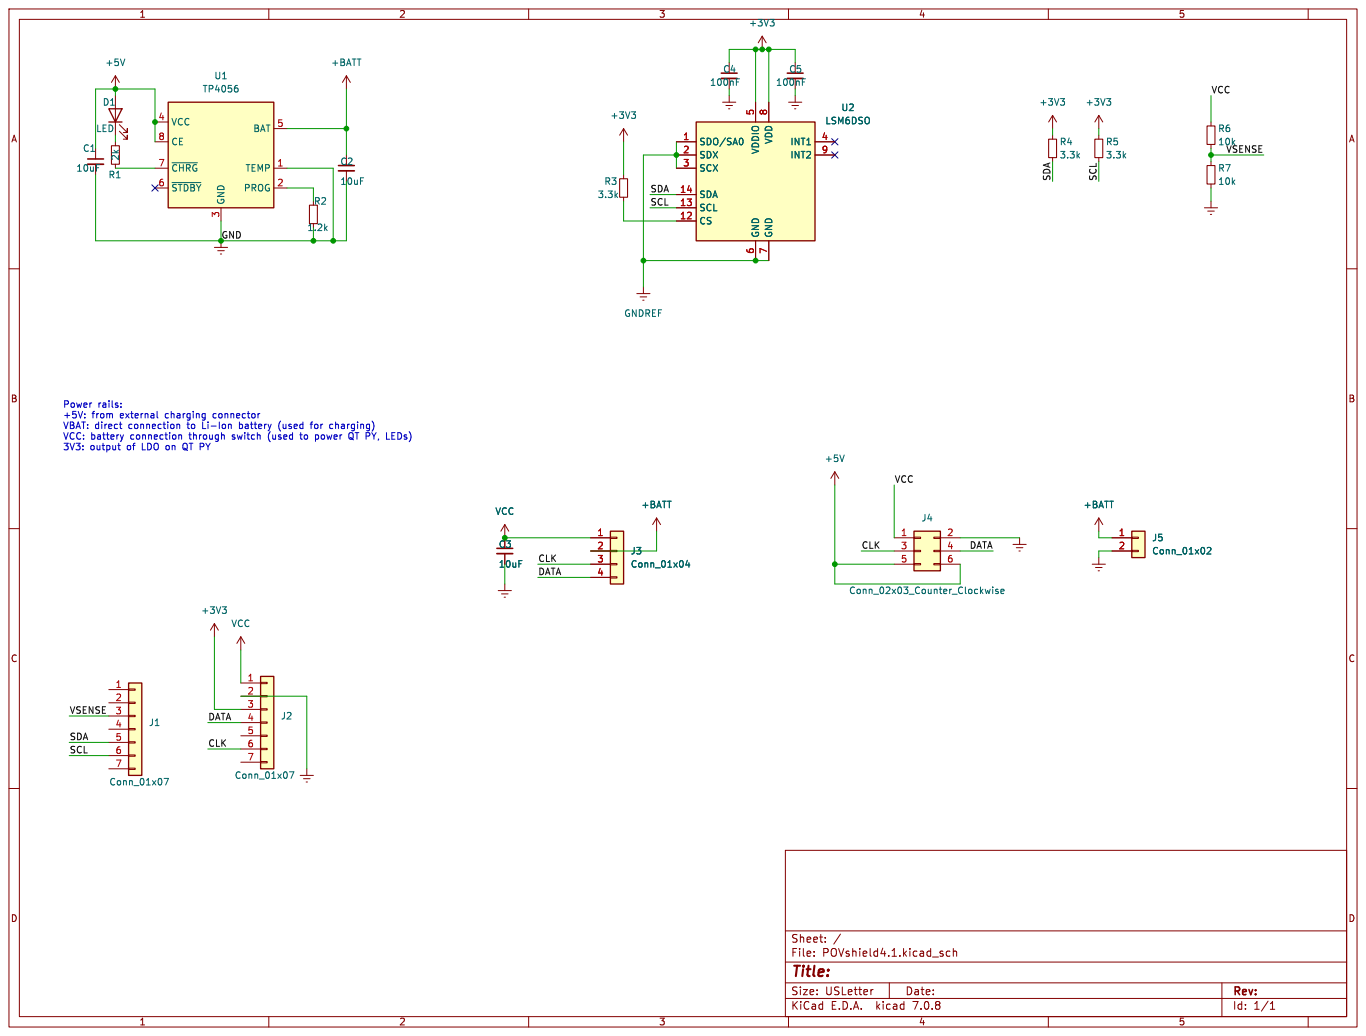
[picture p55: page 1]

3 VCC 4 BAT 5 ~{STDBY} 6 ~{CHRG} 7 CE 8 U1 TP4056 +3V3 D1

Id: 1/1 Title: File: POVshield4.1.kicad_sch Sheet: /

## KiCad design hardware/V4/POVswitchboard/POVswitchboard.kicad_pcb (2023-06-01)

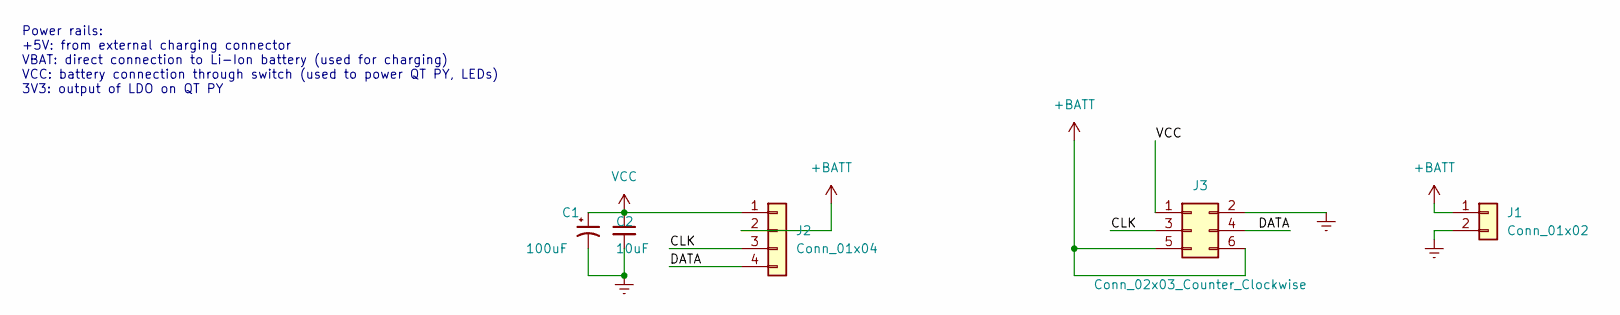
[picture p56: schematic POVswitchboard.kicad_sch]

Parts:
C1: 100uF; CP_Radial_D6.3mm_P2.50mm
C2: 10uF; C_0805_2012Metric; LCSC C15850
J1: Conn_01x02; JST_XH_B2B-XH-A_1x02_P2.50mm_Vertical
J2: Conn_01x04; connector-4p-large-nosilk
J3: Conn_02x03_Counter_Clockwise; PinSocket_2x03_P2.54mm_Horizontal

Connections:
+BATT: J1.1, J2.2, J3.5, J3.6
/CLK: J2.3, J3.3
/DATA: J2.4, J3.4
GNDREF: C1.2, C2.2, J1.2, J3.2
VCC: C1.1, C2.1, J2.1, J3.1

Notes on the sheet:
Power rails: +5V: from external charging connector VBAT: direct connection to Li-Ion battery (used for charging) VCC: battery connection through switch (used to power QT PY, LEDs) 3V3: output of LDO on QT PY

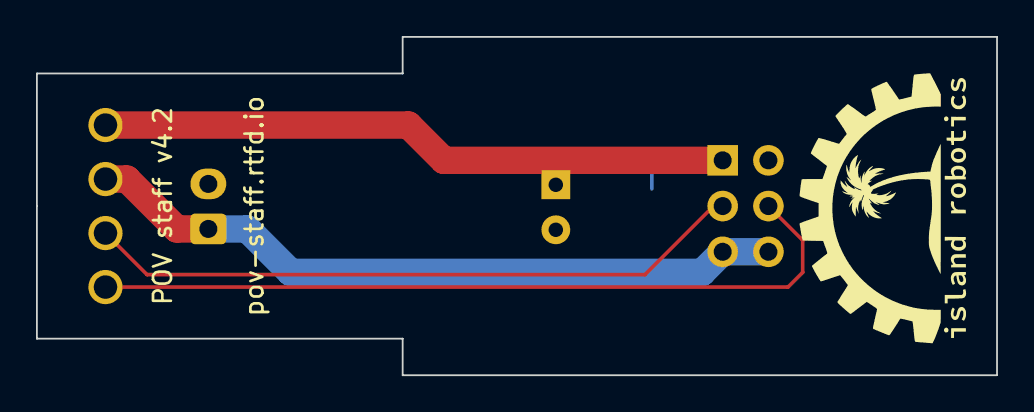
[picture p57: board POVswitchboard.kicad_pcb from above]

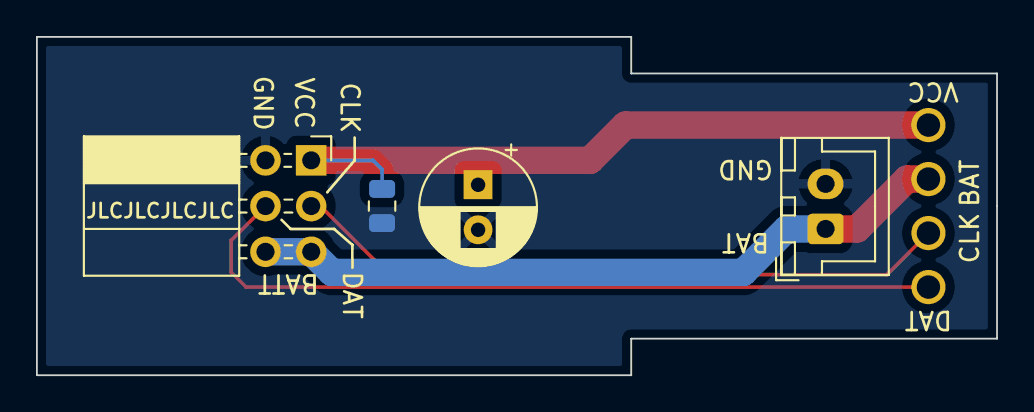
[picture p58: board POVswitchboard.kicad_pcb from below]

Board: 2 copper layers, 53.3 x 18.8 mm, 5 parts (4 on the bottom side), 5 nets.

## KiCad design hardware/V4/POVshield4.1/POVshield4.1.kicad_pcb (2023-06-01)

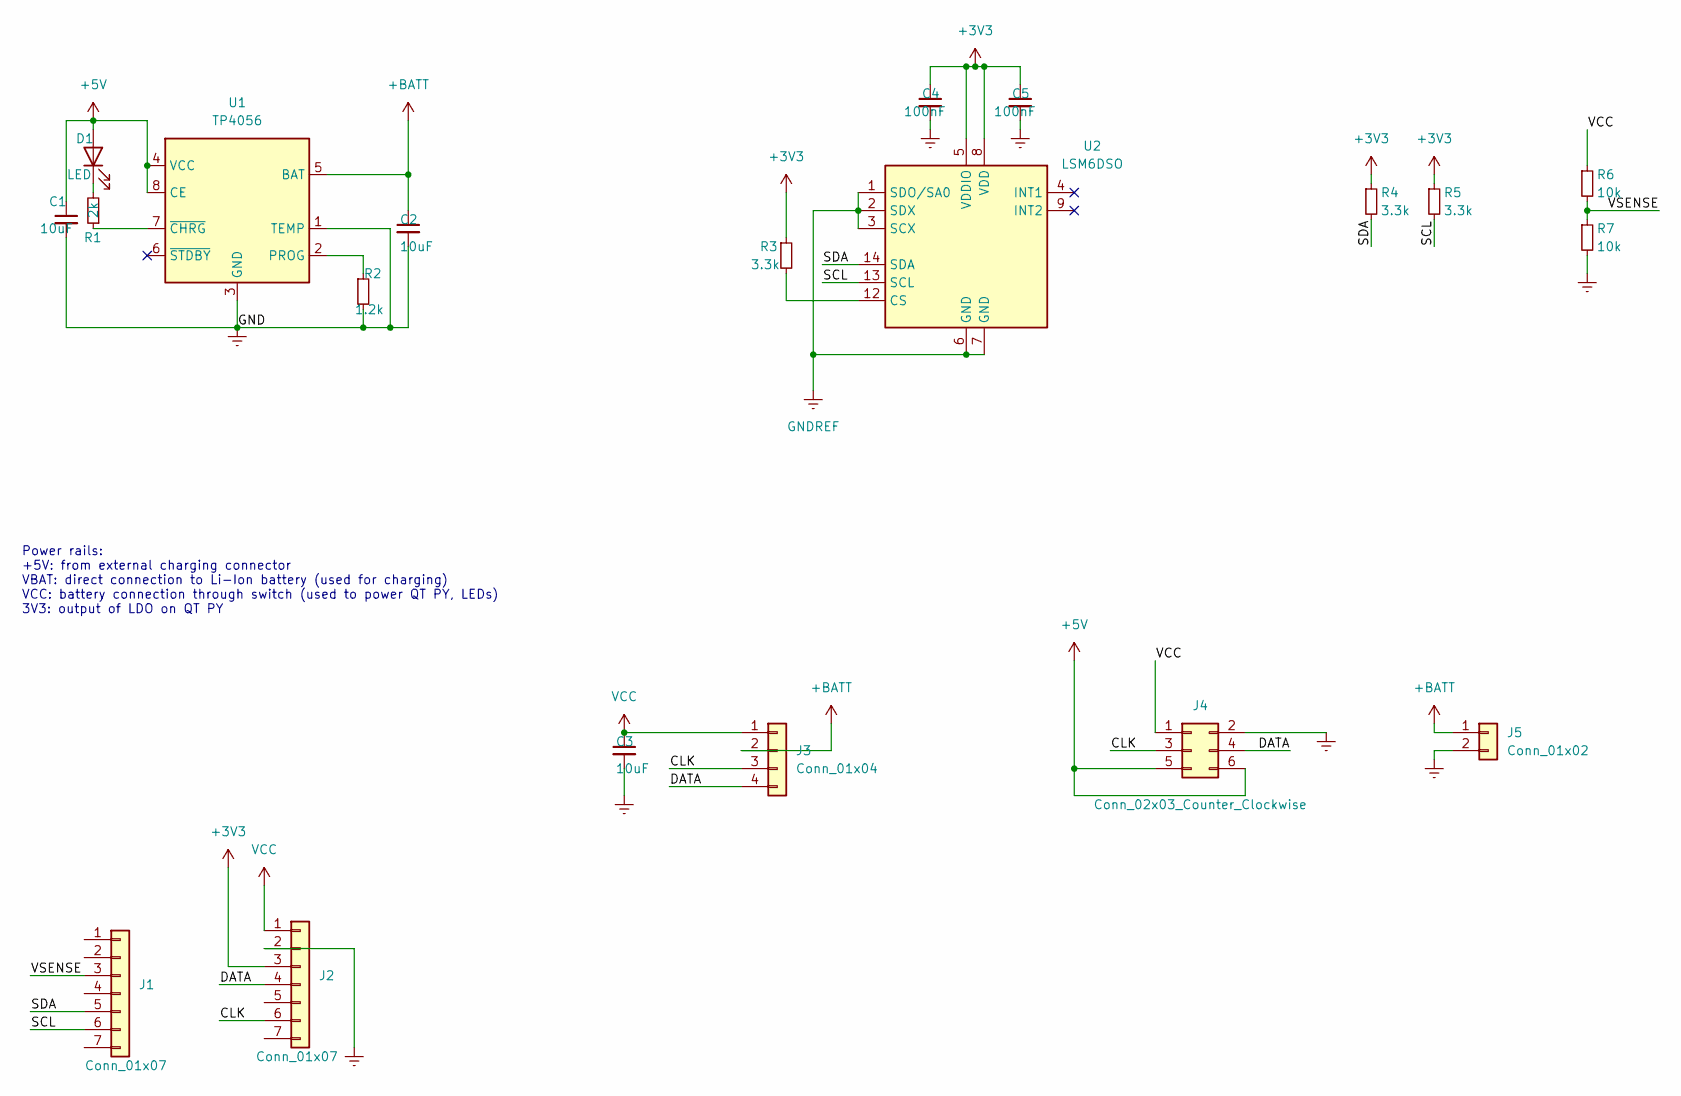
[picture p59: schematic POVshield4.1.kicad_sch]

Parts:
C1, C2, C3: 10uF; C_0805_2012Metric; LCSC C15850
C4, C5: 100nF; C_0603_1608Metric; LCSC C14663
D1: LED; LED_0603_1608Metric; LCSC C72038
J1, J2: Conn_01x07; PinSocket_1x07_P2.54mm_Vertical
J3: Conn_01x04; connector-4p-large-nosilk
J4: Conn_02x03_Counter_Clockwise; PinSocket_2x03_P2.54mm_Horizontal
J5: Conn_01x02; JST_XH_B2B-XH-A_1x02_P2.50mm_Vertical
R1: 2k; R_0603_1608Metric; LCSC C22975
R2: 1.2k; R_0603_1608Metric; LCSC C22765
R3, R4, R5: 3.3k; R_0603_1608Metric; LCSC C22978
R6, R7: 10k; R_0603_1608Metric; LCSC C25804
U1: TP4056; HSOP-8-1EP_3.9x4.9mm_P1.27mm_EP2.41x3.1mm_ThermalVias; LCSC C16581
U2: LSM6DSO; Bosch_LGA-14_3x2.5mm_P0.5mm

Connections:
+3V3: C4.1, C5.1, J2.3, R3.1, R4.1, R5.1, U2.5 (VDDIO), U2.8 (VDD)
+5V: C1.1, D1.2 (A), J4.5, J4.6, U1.4 (VCC), U1.8 (CE)
+BATT: C2.1, J3.2, J5.1, U1.5 (BAT)
/CLK: J2.6, J3.3, J4.3
/DATA: J2.4, J3.4, J4.4
/SCL: J1.6, R5.2, U2.13 (SCL)
/SDA: J1.5, R4.2, U2.14 (SDA)
/VSENSE: J1.3, R6.2, R7.1
EP: C1.2, C2.2, C3.2, C4.2, C5.2, J2.2, J4.2, J5.2, R2.2, R7.2, U1.1 (TEMP), U1.3 (GND), U1.9 (EP), U2.1 (SDO/SA0), U2.2 (SDX), U2.3 (SCX), U2.6 (GND), U2.7 (GND)
unnamed: D1.1 (K), R1.2
unnamed: R1.1, U1.7 (~CHRG)
unnamed: R2.1, U1.2 (PROG)
unnamed: R3.2, U2.12 (CS)
VCC: C3.1, J2.1, J3.1, J4.1, R6.1

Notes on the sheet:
Power rails: +5V: from external charging connector VBAT: direct connection to Li-Ion battery (used for charging) VCC: battery connection through switch (used to power QT PY, LEDs) 3V3: output of LDO on QT PY

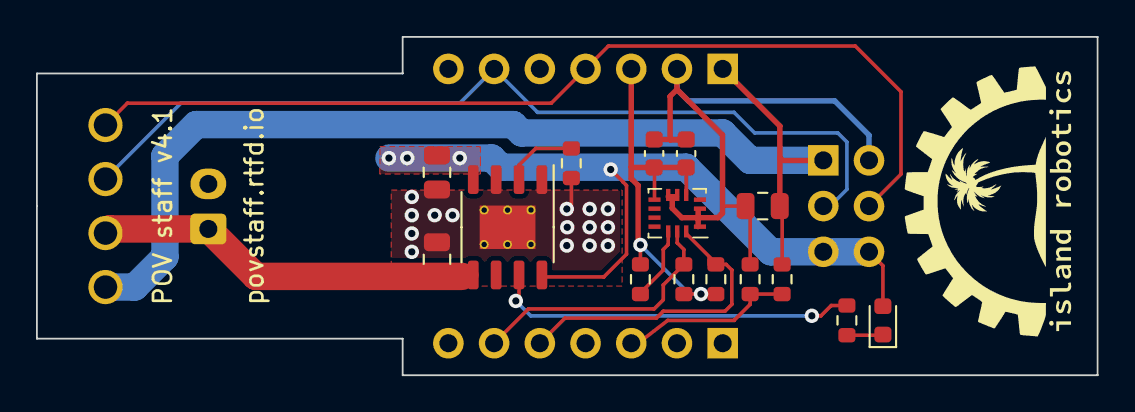
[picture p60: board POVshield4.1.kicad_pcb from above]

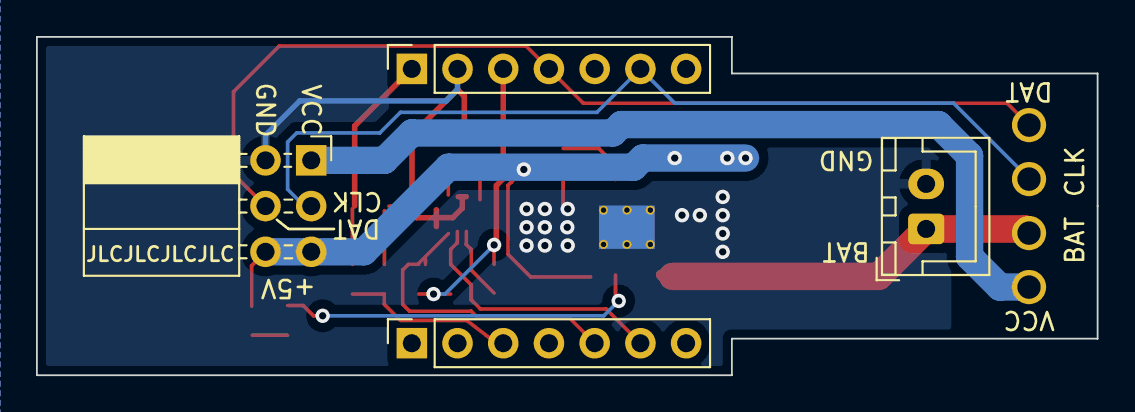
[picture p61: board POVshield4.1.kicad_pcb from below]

Board: 2 copper layers, 58.9 x 18.8 mm, 20 parts (4 on the bottom side), 14 nets.

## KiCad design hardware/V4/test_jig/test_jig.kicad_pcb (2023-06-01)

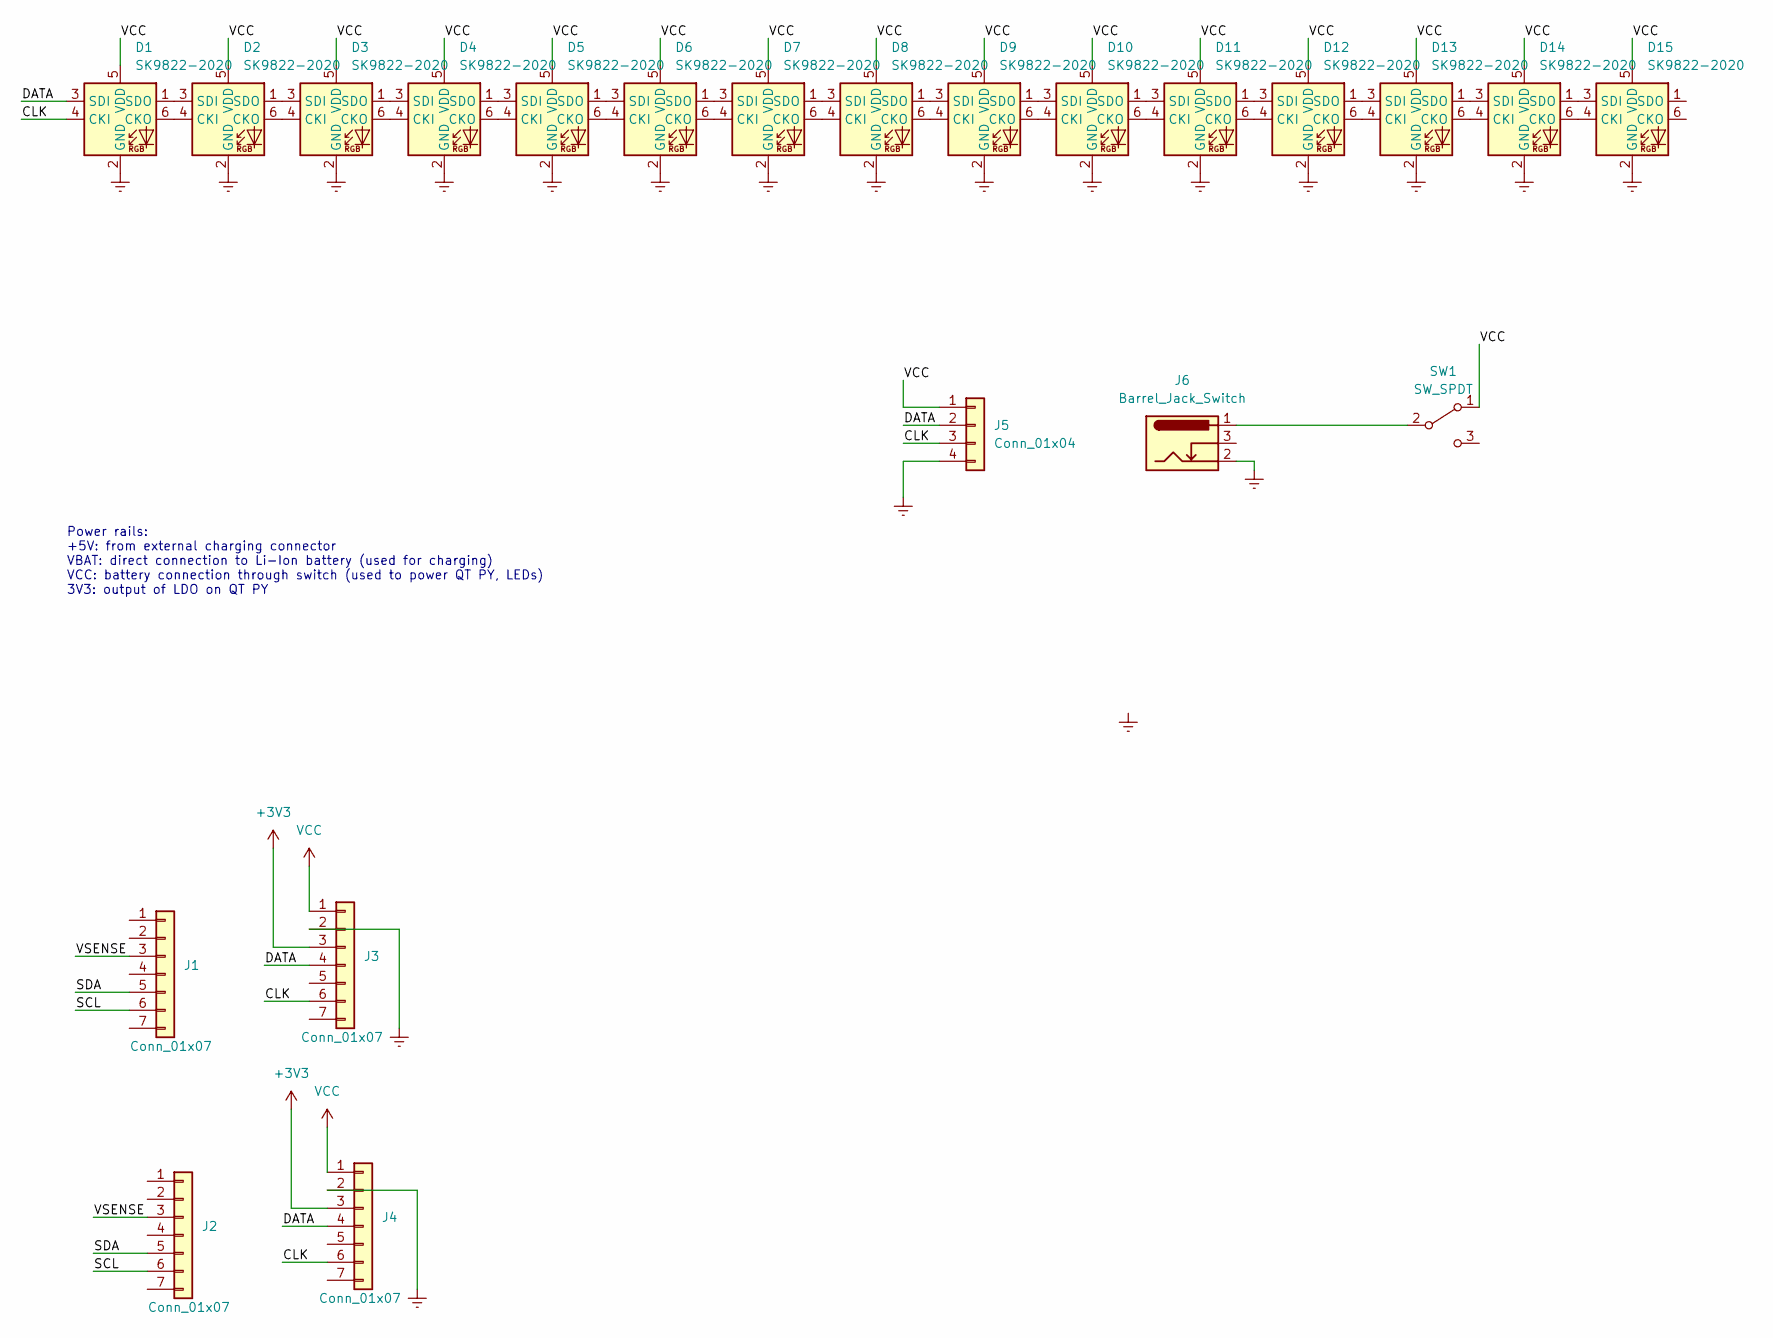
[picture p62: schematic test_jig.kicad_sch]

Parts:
D1, D2, D3, D4, D5, D6, D7, D8, D9, D10, D11, D12, D13, D14, D15: SK9822-2020; LED-SK9822-2020
J1, J2, J3, J4: Conn_01x07
J5: Conn_01x04; connector-4p-large-nosilk
J6: Barrel_Jack_Switch; BarrelJack_GCT_DCJ200-10-A_Horizontal
SW1: SW_SPDT; SW_XKB_SS12D10L3

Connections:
+3V3: J3.3, J4.3
/CLK: D1.4 (CKI), J3.6, J4.6, J5.3
/DATA: D1.3 (SDI), J3.4, J4.4, J5.2
/SCL: J1.6, J2.6
/SDA: J1.5, J2.5
/VSENSE: J1.3, J2.3
GNDREF: D1.2 (GND), D2.2 (GND), D3.2 (GND), D4.2 (GND), D5.2 (GND), D6.2 (GND), D7.2 (GND), D8.2 (GND), D9.2 (GND), D10.2 (GND), D11.2 (GND), D12.2 (GND), D13.2 (GND), D14.2 (GND), D15.2 (GND), J3.2, J4.2, J5.4, J6.2
unnamed: D1.1 (SDO), D2.3 (SDI)
unnamed: D1.6 (CKO), D2.4 (CKI)
unnamed: D2.1 (SDO), D3.3 (SDI)
unnamed: D2.6 (CKO), D3.4 (CKI)
unnamed: D3.1 (SDO), D4.3 (SDI)
unnamed: D3.6 (CKO), D4.4 (CKI)
unnamed: D4.1 (SDO), D5.3 (SDI)
unnamed: D4.6 (CKO), D5.4 (CKI)
unnamed: D5.1 (SDO), D6.3 (SDI)
unnamed: D5.6 (CKO), D6.4 (CKI)
unnamed: D6.1 (SDO), D7.3 (SDI)
unnamed: D6.6 (CKO), D7.4 (CKI)
unnamed: D7.1 (SDO), D8.3 (SDI)
unnamed: D7.6 (CKO), D8.4 (CKI)
unnamed: D8.1 (SDO), D9.3 (SDI)
unnamed: D8.6 (CKO), D9.4 (CKI)
unnamed: D10.1 (SDO), D11.3 (SDI)
unnamed: D9.1 (SDO), D10.3 (SDI)
unnamed: D9.6 (CKO), D10.4 (CKI)
unnamed: D10.6 (CKO), D11.4 (CKI)
unnamed: D11.1 (SDO), D12.3 (SDI)
unnamed: D11.6 (CKO), D12.4 (CKI)
unnamed: D12.1 (SDO), D13.3 (SDI)
unnamed: D12.6 (CKO), D13.4 (CKI)
unnamed: D13.1 (SDO), D14.3 (SDI)
unnamed: D13.6 (CKO), D14.4 (CKI)
unnamed: D14.1 (SDO), D15.3 (SDI)
unnamed: D14.6 (CKO), D15.4 (CKI)
unnamed: J6.1, SW1.2 (B)
VCC: D1.5 (VDD), D2.5 (VDD), D3.5 (VDD), D4.5 (VDD), D5.5 (VDD), D6.5 (VDD), D7.5 (VDD), D8.5 (VDD), D9.5 (VDD), D10.5 (VDD), D11.5 (VDD), D12.5 (VDD), D13.5 (VDD), D14.5 (VDD), D15.5 (VDD), J3.1, J4.1, J5.1, SW1.1 (A)

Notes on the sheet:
Power rails: +5V: from external charging connector VBAT: direct connection to Li-Ion battery (used for charging) VCC: battery connection through switch (used to power QT PY, LEDs) 3V3: output of LDO on QT PY

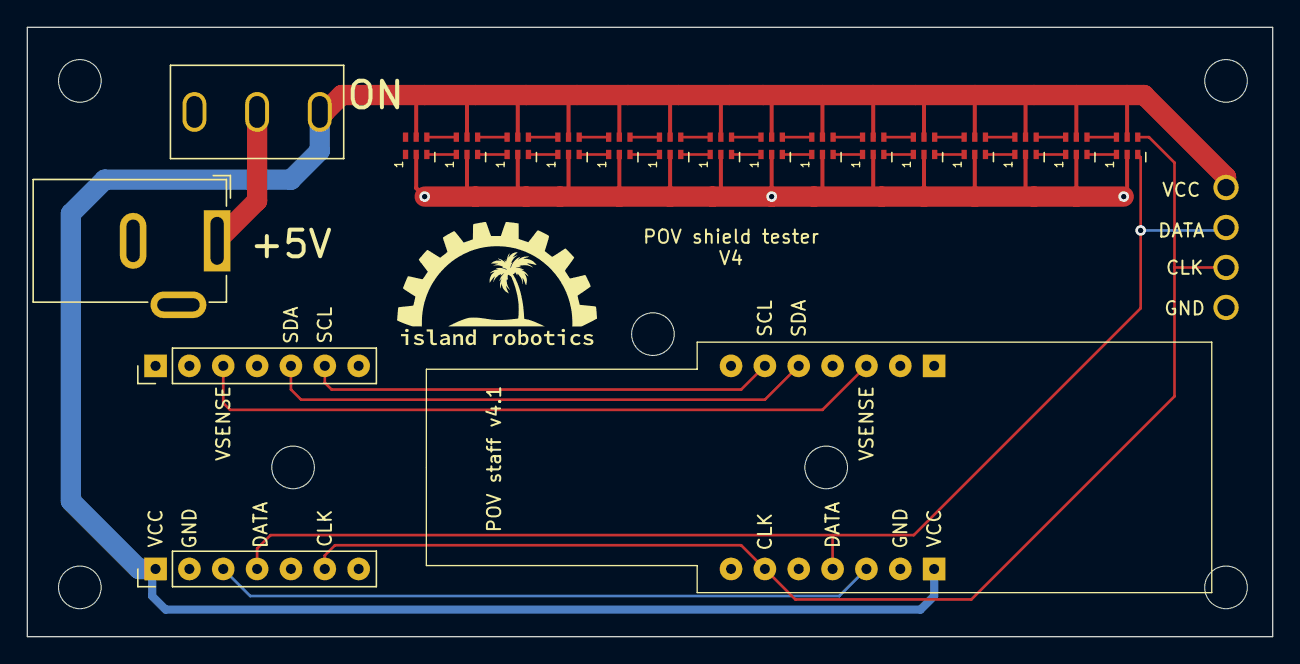
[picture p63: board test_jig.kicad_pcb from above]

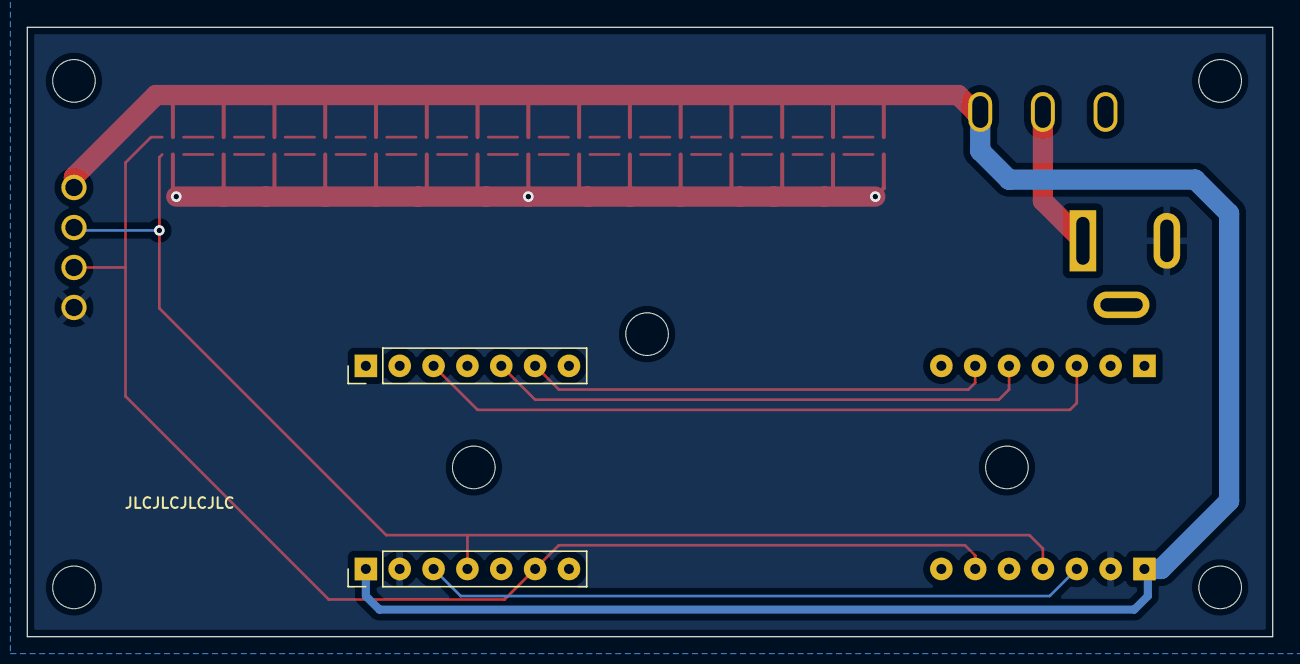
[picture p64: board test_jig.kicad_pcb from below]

Board: 2 copper layers, 93.4 x 45.7 mm, 22 parts (2 on the bottom side), 37 nets.

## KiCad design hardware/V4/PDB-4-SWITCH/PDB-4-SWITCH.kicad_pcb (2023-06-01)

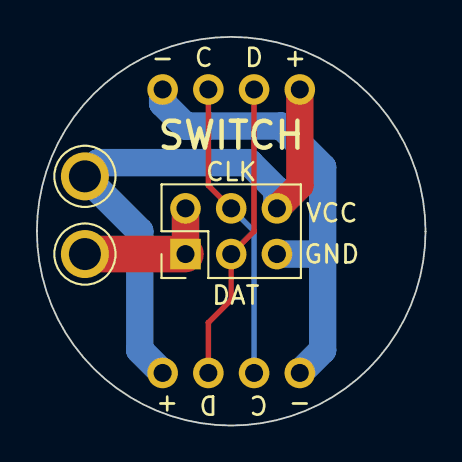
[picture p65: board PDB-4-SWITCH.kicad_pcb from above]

Board: 2 copper layers, 21.6 x 21.6 mm, 5 parts (0 on the bottom side), 5 nets.

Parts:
J1, J2: LED conn; connector-4p-generic-nosilk
J3, J4: Wire solder pad; TestPoint_Plated_Hole_D2.0mm
J5: Conn_02x03_Counter_Clockwise; PinHeader_2x03_P2.54mm_Vertical

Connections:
/CLK: J1.3, J2.3, J5.4
/DAT: J1.2, J2.2, J5.3
/GND: J1.4, J2.4, J5.5
/VBAT: J4.1, J5.1, J5.2
/VCC: J1.1, J2.1, J3.1, J5.6

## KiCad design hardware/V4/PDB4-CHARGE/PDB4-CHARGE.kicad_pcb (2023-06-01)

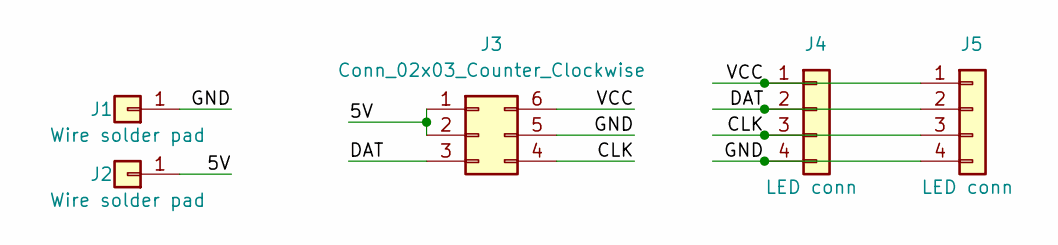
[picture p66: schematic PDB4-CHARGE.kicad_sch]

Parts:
J1: Wire solder pad
J2: Wire solder pad; TestPoint_Plated_Hole_D2.0mm
J3: Conn_02x03_Counter_Clockwise; PinHeader_2x03_P2.54mm_Vertical
J4, J5: LED conn; connector-4p-generic-nosilk

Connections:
/5V: J2.1, J3.1, J3.2
/CLK: J3.4, J4.3, J5.3
/DAT: J3.3, J4.2, J5.2
/GND: J1.1, J3.5, J4.4, J5.4
/VCC: J3.6, J4.1, J5.1

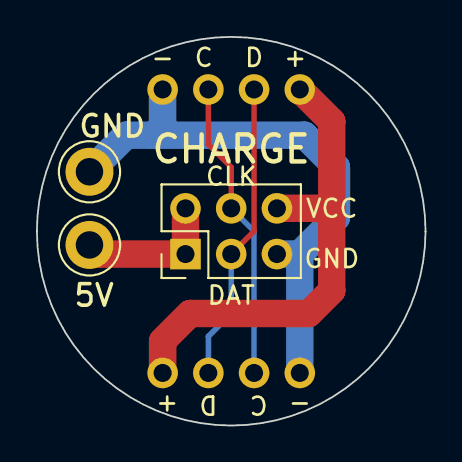
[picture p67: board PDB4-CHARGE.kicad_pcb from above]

Board: 2 copper layers, 21.6 x 21.6 mm, 5 parts (0 on the bottom side), 5 nets.

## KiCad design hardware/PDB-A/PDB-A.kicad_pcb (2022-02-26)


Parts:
J1: Wire sodler pad; TestPoint_Plated_Hole_D2.0mm
J2: JST XH4; JST_XH_B4B-XH-A_1x04_P2.50mm_Vertical
J3: Controller conn; connector-4p-generic-nosilk
J4, J5: LED conn; connector-4p-generic-nosilk

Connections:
/GND: J2.1, J3.1, J4.4, J5.4
/VCC: J1.1, J2.4, J3.4, J4.1, J5.1
unnamed: J2.2, J3.2, J4.2, J5.2
unnamed: J2.3, J3.3, J4.3, J5.3


Board: 2 copper layers, 21.4 x 21.6 mm, 5 parts (0 on the bottom side), 4 nets.

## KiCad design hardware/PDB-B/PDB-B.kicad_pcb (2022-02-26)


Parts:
J1: JST XH4; JST_XH_B4B-XH-A_1x04_P2.50mm_Vertical
J2, J3: LED conn; connector-4p-generic-nosilk
J4: Controller conn; connector-4p-generic-nosilk
J5: Wire sodler pad; TestPoint_Plated_Hole_D2.0mm

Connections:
/GND: J1.1, J2.1, J3.1, J4.1
/VCC: J1.4, J2.4, J3.4, J4.4, J5.1
unnamed: J1.2, J2.2, J3.2, J4.2
unnamed: J1.3, J2.3, J3.3, J4.3


Board: 2 copper layers, 21.4 x 21.6 mm, 5 parts (0 on the bottom side), 4 nets.

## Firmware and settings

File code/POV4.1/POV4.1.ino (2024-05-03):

/*
Persistence of vision  staff project by shurik179
See https://github.com/shurik179/povstaff

Distibuted under MIT license, see LICENSE file in this directory.

For required libraries and support files, check
https://github.com/shurik179/povstaff/code

*/
//first, include all libraries

//NeoPixel
#include <Adafruit_NeoPixel.h>

//Filesystem-related
#include <FS.h>
#include <LittleFS.h>

//WiFi and webserver
#include <WiFi.h>
#include <ESPmDNS.h>
#include <WiFiClient.h>
#include <WiFiAP.h>
#include <WebServer.h>

// Web file manager
#include <detail/RequestHandlersImpl.h>
#include <ESPxWebFlMgr.h>

//our own custom library
#include <pov-esp32.h>
#include "LSM6.h"



// Now, various constants and defines

const word filemanagerport = 8080;
const char *ssid = "POVSTAFFXXXX";
//when choosing a password, you must use at least 8 symbols
const char *password = "XXXXXXXX";
const char *FW_VERSION = "4.1";

// POV Staff details
#define PIN_VSENSE 9
#define NUM_PIXELS 72


// frame rate. Instead of using constant frame rate per second, we will adjust
// depending on rotation speed

// how many degrees of staff turn between successive lines?
#define DEG_PER_LINE 1.0f
// where is the list of images stored?
#define IMAGELIST "/imagelist.txt"
//Finally, some colors
#define RED 0xFF0000
#define GREEN 0x00FF00
#define BLUE 0x0000FF
#define YELLOW 0xFFFF00
#define PURPLE 0x8000FF


// Now, global objects

//the on-board NeoPixel
Adafruit_NeoPixel pixel(1, PIN_NEOPIXEL, NEO_GRB + NEO_KHZ800);


ESPxWebFlMgr filemgr(filemanagerport); // we want a different port than the webserver
WiFiServer server(80);

LSM6 imu;
POV staff(NUM_PIXELS);
uint32_t lastIMUcheck = 0; //when did we last check IMU speed, in ms
uint32_t lastPause = 0;    //when did we last pause/unpause staff, in ms
uint32_t nextImageChange = 0;
float speed=0.0;           //staff rotation speed, in deg/s



void setup() {
    // the usual Serial stuff....
    Serial.begin(115200);
    //deal with on-board neopixel
    pixel.begin();
    pixel.setPixelColor(0,GREEN);
    pixel.show();
    //initialize staff
    Wire.begin();
    staff.begin();
    delay(500);
    //measure battery voltage
    pinMode(PIN_VSENSE, INPUT);
    float voltage = analogReadMilliVolts(PIN_VSENSE)*0.001*2.0;
    staff.showValue(voltage/3.7);
    delay(2000);
    Serial.print("Firmware version: "); Serial.println(FW_VERSION);
    Serial.print("Voltage: "); Serial.println(voltage);
    //clear both the staff and neopixel
    staff.blank();
    pixel.clear();pixel.show();
    // Open LittleFS file system on the flash
    if ( !LittleFS.begin(true) ) {
        Serial.println("Error: filesystem doesn't not exist. Please format LittleFS filesystem");
        while(1) {
            pixel.setPixelColor(0,RED);pixel.show();
            staff.blink();//blink red
        }
    }
    // start the imu
    bool imu_found = imu.init();
    if (!imu_found) {
        Serial.println("Failed to detect and initialize IMU!");
        pixel.setPixelColor(0,YELLOW);pixel.show();
        staff.blink(YELLOW);//blink yellow
    } else {
        imu.enableDefault();
        Serial.println("IMU Enabled");
        staff.blink(GREEN);
    }
    //now, let us check which mode are we in
    delay(1000);
    imu.read();
    if (!imu_found || imu.isHorizontal()){
        //we need to go into uploader mode!
        // let us start wifi, web server etc
        WiFi.softAP(ssid, password);
        IPAddress myIP = WiFi.softAPIP();
        Serial.print("AP IP address: ");
        Serial.println(myIP);
        if (!MDNS.begin("povstaff")) {
              Serial.println("Error setting up MDNS responder!");
              while(1) {
                  pixel.setPixelColor(0,PURPLE);pixel.show();
                  staff.blink(PURPLE);//blink red
              }
        }
        Serial.println("mDNS responder started");
        server.begin();
        MDNS.addService("http", "tcp", 80);
        Serial.println("Server started");
        setupWebserver();
        filemgr.begin();
        Serial.println("Filemanager started");
        //light up staff in green
        staff.blank();
        for (int i=0; 4*i<NUM_PIXELS;i++){
            staff.setPixel(4*i,GREEN); //set every 4th pixel green
        }
        staff.show();
        pixel.setPixelColor(0,GREEN); pixel.show();
        // start webserver loop
        while(1){
            filemgr.handleClient();
            loopWebServer();
        }
    } else {
        //normal mode - showing files from the list
        staff.addImageList(IMAGELIST);
        Serial.println("imagelist added");
        pixel.setPixelColor(0,BLUE); pixel.show();
        staff.paused = true;
    }
}

//Note that loop will only be used in image show mode.
void loop() {
    //check IMU - do we need to pause the show?
    if (millis()-lastIMUcheck > 50 ) {
        //let's check if staff is at rest. To avoid overloading the MCU, we only do it 20 times/sec.
        uint32_t now = millis();
        lastIMUcheck = now;
        imu.read();
        //also, get  rotation speed (in deg/s)
        speed = imu.getSpeed();
        bool atRest=(imu.isVertical() && (speed < 30));
        if (staff.paused && (now - lastPause>1000) && !atRest){
            //if staff was paused for more than 1 sec and is now moving again, resume show
            staff.paused = false;
            //move to new image in the list - unless we are just starting and haven't yet shown any images, which can be detected from lastPause value
            if (lastPause == 0) {
                staff.firstImage();
            } else  {
                staff.nextImage();
            }
            //determine when we will need to change the image
            setNewImageChange();
            lastPause = now;
        } else if (!staff.paused && (now - lastPause>1000) && atRest){
            //staff has been active for more than a  second, and now is stopped
            staff.paused = true;
            staff.blank();
            lastPause = now;
        } else if (staff.paused && (now-lastPause>30000)){
            //blink every 30 seconds to remind the user
            staff.blink();
            lastPause = now;
        }
    }
    if (!staff.paused){
        float rotAngle = speed * staff.timeSinceUpdate() * 0.000001; //total rotation angle since last loop
        if (rotAngle>DEG_PER_LINE) staff.showNextLine();
        if (millis()>nextImageChange) {
            //time to switch to next image
            staff.nextImage();
            setNewImageChange();
        }
    }
}

void setNewImageChange(){
    if (staff.currentDuration() == 0) {
        nextImageChange = ULONG_MAX; //maximal possible unsigned 32-bit int
    } else {
        nextImageChange=millis()+staff.currentDuration()*1000;
    }
}

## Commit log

2020-10-16 Initial commit of code and board design
    [POVshield-V2.0-BOM.csv, POVshield-V2.0-pickandplace.csv, power-dist-board.brd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]
2020-10-21 code update; hardware directory update
    [power-dist-board.brd, power-dist-board.sch, spacer.step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]
2020-12-05 updated docs; spacer model
    [spacer.step]
2021-02-27 updating gerbers
    [POVshield-V2.0-pickandplace.csv]
2022-01-21 Added PDF of power distribution brd
2022-02-26 starting update for 2022 version
    [BOM-POVshield-V3.xlsx, PDB-A.kicad_pcb, PDB-A.kicad_sch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]
2022-03-14 new switch spacer
    [Switch spacer v3.stl, Switch_spacer.step, Switch_spacer.stl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]
2022-03-21 adding PDB3.1; docs update
    [PDB-A-3.1.kicad_pcb, PDB-A-3.1.kicad_sch, PDB-B-3.1.kicad_pcb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]
2022-04-04 new version of spacer
    [PDB-A.kicad_pcb, PDB-A.kicad_sch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]
2022-04-04 fixed file extension for controller wire-1a
2023-06-01 V4 (#2)
    * Version 4 - initial commit
    * V4 cleanup
    * Update README.md
    * hardware directory cleanup
    * updating docs for v4
    * docs - images update
    * docs and 3d printed update
    * docs cleanup
    * docs update
    * docs update
    * docs update
    * docs update
    * docs update
    * docs update
    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
    [BOM-POVshield-V3.xlsx, BOM.xlsx, Battery_endspacer_2023.04.26.f3d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]
2023-06-14 added handout
    [List of parts.xlsx]
2023-07-03 minor update of 3d printed components
    [Charger_spacer_2023.04.26.f3d, Charger_spacer_2023.04.26.stl, Charger_spacer_2023.06.20.f3d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]
2023-10-24 minor changes
    [List of parts.xlsx]
2024-01-02 updated charger spacer
    [Charger_spacer_2023.06.20.f3d, Charger_spacer_2023.06.20.stl, Charger_spacer_2024.01.02.f3d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]
2024-05-03 minor hardware updates
    [List of parts.xlsx]
